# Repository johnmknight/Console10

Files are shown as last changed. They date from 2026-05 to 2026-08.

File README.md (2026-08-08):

<p align="center">
  <picture>
    <source media="(prefers-color-scheme: dark)" srcset="branding/console10_logo_dark.png">
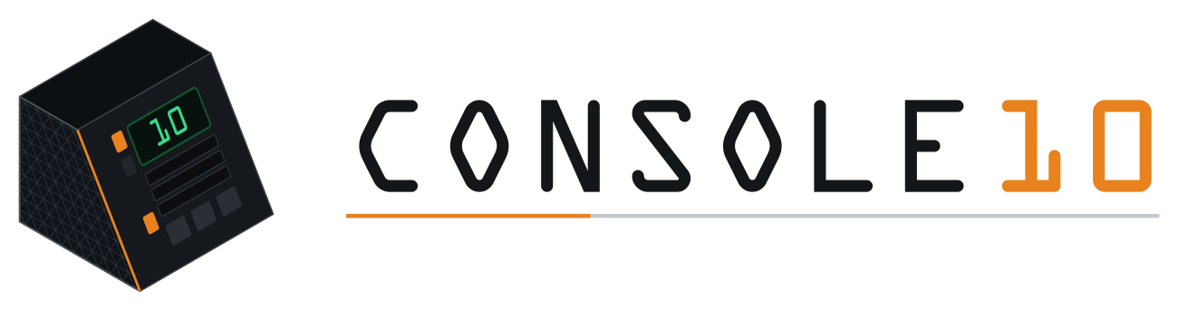
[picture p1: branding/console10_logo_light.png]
CONSOLE10
    
  </picture>
</p>

# Console10

Modular desktop **10" mini-rack housing system**, styled after NASA Mission Operations Control Room consoles. Each module is a self-contained 3D-printed enclosure that houses small-form-factor 10" mini-rack equipment (Pi mounts, small routers, Stream Decks, mini displays).

See `designdoc.md` (**v3.3**) for the full specification, including the accessory faceplates (§15–17).

## Architecture (v3.0)

A module is **4 printed parts**: 2 isogrid **cheeks** + a one-piece **top** + a one-piece **bottom**. The back is an open equipment plane. The **front slant insert is an accessory**, not a cabinet part — see "Cabinet vs. accessories" below. (Corrected 2026-08-01; previously read "5 printed parts".)

The v2.4–v2.5 split-half + centerline-dovetail panel scheme is **abandoned**. Top and bottom are now **single-piece** panels whose width aligns with the 10" mini-rack standard (~253 mm) — so each prints as **one part on a 255 mm bed**. Joinery is **rabbet-based** (no dovetail):

- **Bottom** → raised side ridges seat into **rabbets in the cheek bottom edges**.
- **Top** → a rabbet receives each **cheek's top edge**.
- Secured with glue or fasteners (TBD).

## Cabinet vs. accessories

**"Console10" = the cabinet only**: 2 cheeks + top + bottom. Everything
that mounts to it — display faceplates, the MacroPad panel, the screen/slider panel, blank
fillers, the Gridfinity drawer — is a **swappable accessory faceplate** that bolts to the
cheek **slant inserts** (front) or **back-edge inserts**. Panels are sized to the rack U
grid and the ~253 mm width. `Console10_module.scad` is the fit-check assembly that places
the cabinet + a chosen accessory on the slant.

### Accessory faceplates (current)

| File | Accessory | Mount | Status |
|---|---|---|---|
| `Console10_display_faceplate.scad` | 7" monitor faceplate (Elecrow RC070 / GeeekPi) | 3U slant | v0.17 |
| `Console10_lower_blank_faceplate.scad` | Blank filler beneath the display | 2U slant | v0.1 |
| `Console10_macropad_pair_faceplate.scad` | 2× MacroPad + 0.91" OLED + 6 switch guards | 3U slant | v0.5 |
| `Console10_screen_slider_panel.scad` | 4" HyperPixel sq + NeoSlider fader + OLED + 3 toggle guards | 3U | v0.1 |
| `Console10_dsky_panel.scad` | DSKY-style: HyperPixel + MacroPad + slider + OLED | 3U | v0.1 |
| `Console10_drawer.scad` | Gridfinity slide-out drawer | 2U | WIP v0.1 |
| `Console10_phone_2u_faceplate.scad` | Pixel 10 Pro XL dock: charger puck + eject lever (see `HANDOFF-phone-2u-faceplate.md`) | 2U slant @ s=133.35 | v0.2 |
| `Console10_b860i_faceplate.scad` | ASUS B860-I rear-I/O cover plate (truenas2) | 2U | v0.1 |

Plus assorted blanks / holders (`Console10_aux_2u_faceplate`, `..._bluray_2u_faceplate`,
`..._lcd_simple_faceplate`, `..._sd_holder_handled`, `..._bit_holder_handled`, etc.).

## Repository layout / file status

| File | Role | Status |
|---|---|---|
| `designdoc.md` | Design spec | ✓ v3.3.1 |
| `README.md` | This file | ✓ synced to v3.3.1 (2026-07-28) |
| `Console10_isogrid.scad` | **Cheek** (parametric source) | ✓ v3.1 — rabbets on both top & bottom edges (old v2.4 tab-channels removed) |
| `Console10_isogrid_vent.scad` | Cheek variant: isogrid field cut THROUGH for airflow (drop-in `cheek()` swap; mirrors `Console10_isogrid.scad` — keep in sync) | ✓ v3.0-vent · export `stl/Console10_cheek_vent.stl` |
| `Console10_top.scad` | **Top** panel (parametric source) | ✓ v3.1 |
| `Console10_bottom.scad` | **Bottom** panel (parametric source) | ✓ v3.1 |
| `Console10_front_insert.scad` | **Front** insert (parametric source) | ✓ v3.1 |
| `stl/Console10_cheek.stl` · `stl/Console10_top.stl` · `stl/Console10_bottom.stl` · `stl/Console10_front_insert.stl` | **Current exports — print these** | ✓ 2026-05-28 |
| `NEW_NASA_TOP.stl` · `new_nasa_bottom.stl` · `NASA_Insert_Front.stl` | Reference STL models | superseded by the `.scad` parts |
| `Console10_isogrid-new.stl` | Older cheek export (2026-05-17) | superseded by `stl/Console10_cheek.stl` |
| `Console10_isogrid-do-not-delete.stl` | Old 6 mm cheek | superseded |
| `Console10_top_panel_half.scad` | Split-half top | ✗ DEPRECATED |
| `Console10_bottom_panel_half.scad` | Split-half bottom | ✗ DEPRECATED |
| `Console10_module.scad` | Full fit-check assembly (cabinet + accessory faceplates) | ✓ built |
| `preview/` | Rendered previews | — |
| `marketing/` | Promo materials: storyboard, shot board, video brief | — |
| `wip/` | Scratch: animation runs, logs, backups (untracked except `_parts.py`) | local only |

## Standards (locked)

- **10" mini-rack** (EIA-310-D): 1U = 44.45 mm; rail-to-rail = 236.525 mm; per-U holes at 6.35 / 22.225 / 38.10 mm
- **Equipment mounting**: 10-32 brass heat-set inserts in the cheek edge faces (24 per cheek)
- **Capacity**: 4U (C4)
- **Target bed**: 255 × 255 × 255 mm (all parts single-piece)

## Module dimensions (v3.0)

| Dimension | Value |
|---|---|
| Cheek silhouette | Right trapezoid, slant on FRONT |
| Bottom / depth | **228.6 mm** |
| Back-edge height | **205.45 mm** |
| Top-edge length | **109.975 mm** |
| Front (slant) length | **237.25 mm** |
| Slant angle | **30° from vertical** (isogrid-aligned) |
| Cheek thickness | **10 mm** |
| Top/bottom panel width | **~253 mm** (10" mini-rack standard, single-piece bed-fit) |

## Parts list (4 printed parts + accessories)

**The cabinet — this is what "four printed parts" means:**

| Part | Count | Print orientation |
|---|---|---|
| Cheek (L + R mirror) | 2 | Flat, exterior face down, isogrid up |
| Top panel | 1 | Flat (support rabbet overhang as needed) |
| Bottom panel | 1 | Flat (support ridge overhang as needed) |

**Accessories — printable and legitimate, but never counted in the cabinet:**

| Part | Count | Print orientation |
|---|---|---|
| Front slant insert | 1 | Wedge oriented for minimal support |
| Slant cap | 1 | Glue-on filler; only meaningful with a display faceplate |
| Faceplates (display / macropad / blank / …) | n | See the accessory table above |

*Corrected 2026-08-01 — this heading read "(5 printed parts)" and the table listed the
front insert as a cabinet part. The authoritative lists are `CABINET_PARTS` and
`ACCESSORY_PARTS` in `Console10_module.scad`, which `wip\_parts.py` parses with no
fallback, so any render's part count now comes from the SCAD rather than from this table.*

## OpenSCAD usage

```
openscad Console10_isogrid.scad     # cheek (parametric)
openscad Console10_module.scad      # full fit-check assembly (built)

# headless export of the whole cabinet, no faceplates:
openscad -o module.stl -D show_front=true -D show_macropad=false \
         -D show_display=false -D show_lower_blank=false Console10_module.scad
```

**All four cabinet parts are parametric SCAD** as of v3.1 — `Console10_isogrid.scad`, `Console10_top.scad`, `Console10_bottom.scad`, `Console10_front_insert.scad`. `Console10_module.scad` `use<>`s all four and places them; that file is the authority on how the parts seat. Current exports are in `stl/`. The root-level `NEW_NASA_TOP.stl`, `new_nasa_bottom.stl` and `NASA_Insert_Front.stl` are the earlier hand-modelled generation, kept for reference only — they are not byte-identical to the current exports even where bounding boxes match, so don't print from them.

## Open items

See `designdoc.md` §13. Highlights: reconcile final width vs rabbet geometry; finalize glue vs fasteners; first-print validation of the 0.4 mm ridge/rabbet clearance; decide front-insert merge-into-bottom vs standalone + glue.

Closed since this list was written: the cheek tab-channels **were** replaced with rabbets (v3.1, both top and bottom edges), the front wedge **is** 30° and mates flush, and `Console10_module.scad` **is** built.

Closed 2026-08-01: `Console10_module.scad` used to draw `slant_cap_on_slant()` unconditionally; it is now gated behind `show_slant_cap` (default off — only meaningful with `show_display` on).

## Variants

- **C4** (4U, current) · C2 (2U, future) · C6 (6U, future) · C4-E (sci-fi etched, deferred)

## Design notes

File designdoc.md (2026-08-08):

# CONSOLE10 — DESIGN DOCUMENT

**Version 3.3.1**
**Date: 2026-07-28**

---

## v3.3.1 changelog — documentation only, no geometry change

An audit against the files on disk found the doc contradicting itself in four places.
No part was modified; only the descriptions of them.

1. **§3.1 parts table** pointed at the superseded root-level STLs (`NEW_NASA_TOP.stl`,
   `new_nasa_bottom.stl`, `NASA_Insert_Front.stl`, `Console10_isogrid-new.stl`) while §7
   and §12 said the parametric `.scad` files supersede them. Now points at `stl/`, which
   holds the current exports.
2. **§9.2** listed the top as 16 mm thick and the front insert as 237.3 × 20.6 — the
   dimensions of the *old* STLs, contradicting §7. Corrected to the measured current
   parts (top 10 mm; insert 232.6 × 21.9 × 38).
3. **§12** labelled this file "✓ v3.1" while the header said v3.3, and omitted `stl/`
   entirely. Both fixed.
4. The **slant cap** (`Console10_slant_cap.scad`) was undocumented. It is an *accessory*,
   not a fifth-part-plus-one: a glue-on filler for the gap between the top panel and the
   top of a fitted display faceplate. `Console10_module.scad` used to draw
   `slant_cap_on_slant()` **unconditionally**, with no `show_` flag — fixed alongside this
   audit: it is now gated behind `show_slant_cap` (default off, since it is only
   meaningful when `show_display` is on).

## v3.3 changelog (vs v3.1)

1. **Top front bevel** added (built cleanly via `hull()`) — the top's front edge rakes to the 30 deg slant.
2. **M3 mounting screws**: socket-cap, **counterbored flush** — top **3/side**, bottom **4/side**, centered over each cheek — driving into **M3 heat-set inserts** in the cheek top + bottom edges.
3. **Tongue & groove equalized**: tongue + both walls all equal at 10/3 (~3.33 mm), centered (was a 4 mm tongue offset to the inside, unequal walls).
4. **Isogrid moved to the EXTERIOR face**, **5 mm deep** (was 1.8 mm on the interior), with the **outer ring filled solid** (`iso_edge_fill`, ~half a triangle spacing) so the deeper pockets clear the edge rabbets / inserts / rail holes.

## v3.1 changelog (vs v3.0)

1. **All parts are now parametric OpenSCAD**: `Console10_top.scad`, `Console10_bottom.scad`, `Console10_front_insert.scad` (reverse-engineered from the NASA STL models), plus the existing cheek `Console10_isogrid.scad` and an assembly `Console10_module.scad`.
2. **Symmetric ridge joinery**: the TOP now uses the SAME joinery as the bottom — a slab with two side ridges that seat into rabbets in the cheek **top** edge. The v3.0 top "wall + slot" scheme is dropped. The cheek now has a rabbet on **both** the top and bottom edges.
3. **Front insert** now spans BETWEEN the cheeks (~232.6 mm), sitting on the floor at the front, with its 30° face flush with the slant (was modeled as a slant-length wedge).
4. A 30° bevel on the top's front edge was tried and reverted here (re-added cleanly in v3.3).

## v3.0 changelog (vs v2.5) — MAJOR ARCHITECTURE CHANGE

The split-half + dovetail-castellation panel scheme (v2.4–v2.5) is **abandoned**. Top and bottom are now **single-piece panels** sized to the 10-inch mini-rack standard width, and joinery is **rabbet-based**, not centerline-dovetail.

1. **Top & bottom panels are one piece each** — no L/R split, no centerline dovetail. Their width now aligns with the **10" mini-rack standard (~253 mm)**, so each panel **prints as a single part on a 255 × 255 × 255 mm bed**. The bed-fit split that drove the v2.4 dovetail design is no longer needed.
2. **Joinery is now rabbet-based** (replaces cheek tab-channels + centerline dovetail):
   - **Bottom**: a **raised ridge along each side** seats into a matching **rabbet in the cheek's bottom edge** (one ridge per side).
   - **Top**: a **rabbet** on the top that **each cheek's top edge sits into**.
   - Final hold: **glue or fasteners** (type TBD).
3. **Front insert added** (`NASA_Insert_Front.stl`): a slant-length wedge **template** that can either be **merged into the bottom** part or **printed standalone and glued** along the slant.
4. **Top / bottom / front are now standalone STL models**, not SCAD-generated. The **cheek remains SCAD-driven** (`Console10_isogrid.scad`).
5. **Deprecated**: `Console10_top_panel_half.scad`, `Console10_bottom_panel_half.scad`, the centerline dovetail (old §8), and the cheek top/bottom **tab-channels** (old §6) — the cheek now needs **rabbets** instead of channels (SCAD update pending, see §12).

(Changelogs v2.1–v2.5 retained in §14 for history.)

---

## 1. What we're building

Console10 is a modular 10-inch mini-rack housing for desktop equipment, 3D-printed in PLA, styled after Apollo-era NASA mission-control hardware.

A module is **four printed parts**: two trapezoidal isogrid **cheeks** (L/R sides), a single-piece **top** panel, and a single-piece **bottom** panel. The **back** face is an open equipment-mounting plane; 1U faceplates are user-installed. The **front slant** is also a mounting plane.

The **front slant insert** is an **accessory**, not a cabinet part — optional filler/template for the front slant, in the same category as the slant cap and the faceplates. Corrected 2026-08-01; this line previously read "five printed parts" and counted the insert. The authoritative lists live in `C:\Users\john_\dev\Console10\Console10_module.scad` as `CABINET_PARTS` and `ACCESSORY_PARTS`, which `C:\Users\john_\dev\Console10\wip\_parts.py` parses with no fallback — so the count in any render now comes from the SCAD rather than from prose. (Local, untracked backup of the previous version: `wip\_pre0801_designdoc.md.bak`, sha256 prefix `410F8B750A28F9A8` — `*.bak` is gitignored, so it exists only on JOHN-S-PC.)

Panels register to the cheeks via **rabbet joinery** (§6–7) and are secured with glue or fasteners.

---

## 2. Standards compliance

- **Mounting standard**: EIA-310-D 10-inch mini-rack
- **1U height**: 44.45 mm
- **Per-U hole pattern**: 3 holes at offsets 6.35, 22.225, 38.10 mm
- **Capacity**: 4U (C4 variant)
- **Rail-to-rail hole spacing**: 236.525 mm
- **Panel width**: aligned to the 10" mini-rack standard (~253 mm)

---

## 3. Module architecture

### 3.1 Parts list (5 parts per module)

| Part | Count | File (current) | Source | Role |
|---|---|---|---|---|
| Cheek | 2 | `stl/Console10_cheek.stl` | `Console10_isogrid.scad` | Side panel, right-trapezoid, isogrid, 10 mm thick |
| Top | 1 | `stl/Console10_top.stl` | `Console10_top.scad` | Caps the top edge; ridges seat into the cheek top-edge rabbets |
| Bottom | 1 | `stl/Console10_bottom.stl` | `Console10_bottom.scad` | Floor; raised side ridges seat into cheek bottom-edge rabbets |
| Front insert | 1 | `stl/Console10_front_insert.stl` | `Console10_front_insert.scad` | Slant filler spanning between the cheeks; merge into bottom or print standalone + glue |

**Current exports live in `stl/`.** The root-level `Console10_isogrid-new.stl` (2026-05-17),
`new_nasa_bottom.stl`, `NEW_NASA_TOP.stl` and `NASA_Insert_Front.stl` (all 2026-05-28 morning)
predate the parametric sources and are retained for reference only — see §12. They are NOT
byte-identical to the current exports even where the bounding boxes match, so do not print
from them.

No split halves, no separate rails, no centerline dovetail. Rail-mount holes are integral to each cheek's edge faces (§5).

### 3.2 Material

Default **PLA**. PETG/ASA acceptable for cheeks. (Solvent-bond requirement from the old dovetail design no longer applies; bonding is now at the rabbet interfaces if glue is used.)

### 3.3 Hardware BOM (per module)

| Item | Count | Use |
|---|---|-----|
| 10-32 brass heat-set inserts | 48 | Equipment mounting (24 per cheek: 12 slant + 12 back) |
| Glue or fasteners | as required | Top/bottom-to-cheek at the rabbet interfaces (type TBD) |

---

## 4. Cheek

### 4.1 Silhouette (LOCKED, unchanged)

Right trapezoid, slant on the **front** edge.

| Edge | Length (mm) |
|---|---|
| Bottom | 228.6 |
| Back (vertical) | 205.45 |
| Top | 109.975 |
| Slant (front) | 237.25 |
| Slant angle | 30° from vertical (isogrid-aligned) |

### 4.2 Thickness — 10 mm

Hosts ~8 mm-deep edge-drilled 10-32 inserts with adequate wall material.

### 4.3 Isogrid (v2.5)

- Tiling: {3, 6} triangular · Spacing: 20 mm · Rib: 2.5 mm · **Pocket depth: 5 mm** (or through-cut) · Fillet: 1.59 mm
- **Face: EXTERIOR** (v3.3 — pockets are on the outside face; interior is flat)
- Coverage: **whole-triangle filter** + **outer-ring fill** — a pocket is generated only when all three triangle vertices fall inside the silhouette inset by `iso_edge_fill` (~half a spacing). This fills the outer ring(s) solid so the 5 mm pockets clear the edge rabbets / inserts / rail holes.

### 4.4 Cheek edge features for panel joinery (v3.0 — pending SCAD update)

- **Bottom edge**: a **rabbet** to receive the bottom panel's raised side ridge.
- **Top edge**: seats into the rabbet on the top panel (the cheek top is the male feature here).
- NOTE: the current `Console10_isogrid.scad` still models the **old tab-channels** (`top_channel()` / `bottom_channel()`) on these edges. These must be replaced with rabbets to match v3.0. See §12.

---

## 5. Equipment mounting (cheek edges)

Rack equipment mounts via flanged rack ears bolted directly to the cheek **edge face**, into heat-set inserts in the cheek thickness. The cheek edge IS the mounting surface — no separate rail.

### 5.1 Slant edge rail
- 12 × 10-32 insert holes, axis perpendicular to slant face, EIA-310 pattern, 4U, 1U bottom gap, 15 mm top margin.
- Positions along slant from front-bottom corner (mm): `50.80, 66.675, 82.55, 95.25, 111.125, 127.00, 139.70, 155.575, 171.45, 184.15, 200.025, 215.90`
- Hole: 4.2 mm dia (10-32 pilot), 8 mm deep.

### 5.2 Back edge rail
- 12 × 10-32 insert holes, axis perpendicular to back face, EIA-310 pattern, 4U from floor.
- Positions from floor (mm): `6.35, 22.225, 38.10, 50.80, 66.675, 82.55, 95.25, 111.125, 127.00, 139.70, 155.575, 171.45`
- Same hole dia/depth as slant.

---

## 6. Cheek ↔ panel rabbet joinery (replaces old §6 channels + §8 dovetail)

- **Bottom**: raised ridge on each side of the bottom panel → rabbet in the cheek bottom edge. Registers the floor laterally and locates the cheeks.
- **Top**: raised ridge on each side of the top panel → rabbet in the cheek **top** edge (symmetric with the bottom — same joinery both ends).
- **Securing**: glue or fasteners across the rabbet interfaces (TBD).
- Exact ridge/rabbet dimensions and clearances: **TBD** — to be set when the cheek SCAD is updated and the panels are dimensioned against it.

---

## 7. Top, bottom, and front parts (measured, as-modeled)

| Part | W × D × H (mm) | Notes |
|---|---|---|
| **Top** (`Console10_top.scad`) | 253 × 109.975 × 10 | Slab (6 mm) + two 4×4 side ridges. Ridges seat into the cheek **top** rabbets (flipped in the module). One-piece. |
| **Bottom** (`Console10_bottom.scad`) | 253 × 228.6 × 10 | Slab (6 mm) + two 4×4 side ridges → cheek **bottom** rabbets. One-piece. |
| **Front insert** (`Console10_front_insert.scad`) | ~232.6 × 21.94 × 38 | Triangular wedge spanning BETWEEN the cheeks, on the floor at the front; 30° face flush with the slant. Print standalone + glue, or merge into the bottom. |

(The original `NEW_NASA_TOP.stl` / `new_nasa_bottom.stl` / `NASA_Insert_Front.stl` models are retained for reference; the parametric `.scad` files above supersede them.)

The 253 mm width aligns with the 10" mini-rack standard and fits a 255 mm bed as a single part — no split required.

---

## 8. Centerline joint — REMOVED

The v2.4–v2.5 trapezoidal dovetail castellation at the panel centerline is **superseded** by the single-piece panels + rabbet joinery (§6). There is no centerline split in v3.0.

---

## 9. Manufacturing

### 9.1 Print bed
255 × 255 × 255 mm (also fits Bambu A1/P1/X1 256 mm class).

### 9.2 Fit on bed (all single-piece)

| Part | Footprint (mm) | Thickness/Height | Fits 255 bed |
|---|---|---|---|
| Cheek | 228.6 × 205.45 | 10 mm | ✓ |
| Top | 253.0 × 110.0 | 10 mm | ✓ |
| Bottom | 253.0 × 228.6 | 10 mm | ✓ |
| Front insert | 232.6 long | 21.9 × 38 | ✓ |

(Measured from the current `stl/` exports, 2026-07-28. The earlier "Top 16 mm" and
"Front insert 237.3 long × 20.6" figures described the superseded root-level STLs and
contradicted §7; both now agree.)

### 9.3 Print orientation
- **Cheek**: flat on bed, **interior face down** (the isogrid is now on the exterior, so its pockets face up — no overhang). M3 insert holes in the top/bottom edges; rail holes in the slant/back edges.
- **Top / bottom**: flat on bed (rabbet/ridge features may need light support depending on orientation).
- **Front insert**: orient wedge for minimal support.

### 9.4 Suggested settings (PLA)
- 0.2 mm layers, 25–40% infill, 3–4 walls, supports as needed for rabbet/ridge overhangs.

---

## 10. Module exterior dimensions

| Dimension | Value (mm) |
|---|---|
| Depth (bottom front-to-back) | 228.6 |
| Height (back edge) | 205.45 |
| Slant length | 237.25 |
| Top edge length | 109.975 |
| Top/bottom panel width | ~253 (10" mini-rack standard) |

(Old v2.x interior/exterior width figures of 261.525 / 281.525 are superseded; reconcile final width against the rabbet geometry — see §13.)

---

## 11. Variants

| Variant | Description | Status |
|---|---|---|
| **C4** | 4U, standard | current |
| C2 | 2U (shorter) | future |
| C6 | 6U (taller) | future |
| C4-E | C4 with sci-fi etching | deferred |

---

## 12. Files

| File | Status |
|---|---|
| `designdoc.md` (this file) | ✓ v3.3.1 |
| `stl/` — **current exports**: `Console10_cheek.stl`, `Console10_top.stl`, `Console10_bottom.stl`, `Console10_front_insert.stl` | ✓ exported 2026-05-28 13:36 from the parametric sources |
| `stl/All-Parts.3mf` | slicer project (ignored by git — `*.3mf`) |
| `stl/nasa switch  guards/` | printable toggle-switch guards |
| `Console10_slant_cap.scad` / `_tall` | accessory: glue-on filler closing the slant between the top panel and the top of the display faceplate. NOT a cabinet part — only needed when a display faceplate is fitted |
| `README.md` | ✓ (v3.0 layout; minor v3.1 joinery sync pending) |
| `Console10_isogrid.scad` (cheek) | ✓ v3.1 — silhouette/isogrid + rabbets on both top & bottom edges |
| `Console10_top.scad` | ✓ v3.1 — slab + side ridges (parametric) |
| `Console10_bottom.scad` | ✓ v3.1 — slab + side ridges (parametric) |
| `Console10_front_insert.scad` | ✓ v3.1 — front wedge, spans between cheeks (parametric) |
| `Console10_module.scad` | ✓ v3.1 — fit-check assembly (use<> all parts) |
| `NEW_NASA_TOP.stl` / `new_nasa_bottom.stl` / `NASA_Insert_Front.stl` | reference STL models (superseded by the `.scad` parts) |
| `Console10_top_panel_half.scad` / `..._bottom_panel_half.scad` | ✗ DEPRECATED (split-half design) — safe to delete |
| `Console10_isogrid-do-not-delete.stl` | old 6 mm cheek (superseded) |

---

## 13. Open items

- **Reconcile module width**: panels are 253 mm; confirm final interior/exterior width and rabbet engagement against the cheeks (old 261.525 interior is superseded).
- **Front insert**: decide merge-into-bottom vs standalone + glue.
- **Securing method**: finalize glue vs fasteners for top/bottom-to-cheek.
- **Ridge/rabbet fit clearance**: first-print validate the 0.4 mm clearance.
- **Shared params**: consider a `Console10_params.scad` so the ridge/rabbet dims can't drift between the cheek and the panels.
- **MiniRax faceplates** (`MiniRaxFacePlate1.stl`, `MiniRax-plain-mini-faceplate.stl`): integrate / parameterize as needed.

---

## 15. Slide-out Gridfinity drawer — WIP v0.1 (2026-05-30)

A 2U slide-out drawer for the module BOTTOM whose floor is a true Gridfinity
baseplate. New file: `Console10_drawer.scad` (parametric; `part =
"faceplate"|"drawer"|"assembly"`). Compiles clean + manifold in OpenSCAD;
fit-check previews at `preview/drawer_assembly_iso.png` / `_side.png`.

**Architecture (locked with John):** faceplate-anchored, no floor hardware.
- The **faceplate** is a 30° slanted bezel that bolts to the cheek **slant** rack
  inserts (2 screws/side). Its two **C-channel slide rails are integral**, running
  back along the floor into the cavity. It REPLACES `Console10_front_insert` on a
  drawer module.
- The **drawer** is a 5×4 Gridfinity box (210×168 mm field, standard 4.75 mm
  interface) with side **tongues** riding the rails; its own 30° front nests
  flush in the faceplate mouth (finger-pull slot).

**Key params (as built):** face 247×87.9 mm, mouth 222×74 mm; drawer body
220×183 mm; rail 8 mm / 6 mm slot, tongue 4×5 mm, `run_gap` 0.5; Gridfinity
pitch 42, no-magnet "lite" baseplate.

**NEXT STEPS to make it print-ready (none are open design questions):**
1. **Drawer stop** — add a rear bump-stop in the rails + a removable front
   retainer so the drawer can't pull fully out. (Not yet modeled.)
2. **Rail overhang** — the C-channel lip overhangs its slot; add a 45° chamfer
   under the lip and/or a split-rail print option. Decide print orientation.
3. **Fit validation (first article):** tongue/slot `run_gap` and the Gridfinity
   pocket fit are first-print tuning items.
4. **Docs:** fold this into the README parts table + a designdoc v3.4 changelog
   and the variants list once the geometry is frozen.

**State:** `Console10_drawer.scad` is untracked (not committed). Previews are new
files in `preview/`. Nothing else in the repo was changed.

---

## 16. Twin-MacroPad lower faceplate — v0.4 (2026-06-14)

A plain 2U faceplate (`Console10_macropad_pair_faceplate.scad`; `part =
"panel" | "mount_board" | "macropad_backplate"`) carrying **two Adafruit 5128
MacroPad RP2040s** mounted end-to-end, each rotated 90° so the long axis runs
across the panel (OLED/encoder ends out at the far left/right, PCBs butt at the
centre seam). Each board drops into a rear pocket+collar; keys stay proud through
the front.

**Two bolt circles per pad (this is the key geometry).** The MacroPad's own PCB
holes and the panel's backplate posts are **deliberately not concentric**:
- **PCB mounting holes** — pitch `mp_hx,mp_hy` = 52.07 × 81.28 mm (±26.04 × ±40.64),
  **but the 4-hole pattern is NOT centred on the board.** Measured from the 5128
  assembly STL (cross-sectioned + overlaid in OpenSCAD — *measure from the model,
  not photos*), it sits **`mp_hy_off` = +7.65 mm toward the OLED/encoder (+Y) end**.
  Holes are at (±26.04, ±40.64 **+ 7.65**). The earlier v0.2 board placed the
  standoffs centred, so they missed every hole by ~7.6 mm and the two pads could
  not be mounted back-to-back — this is the v0.3 fix.
- **Panel posts** — `mp_post_sx,mp_post_sy` = ±38 × ±44, pushed *outboard* of the
  pocket/collar wall (which reaches 32.65) so a backplate can bolt to the panel
  clear of the board. A Ø7 post can't sit on the PCB-hole axis without fouling the
  board, so the two circles stay offset by ~12 mm (across) / ~3.4 mm (along).
  (Seen edge-on this reads as "posts offset from the MacroPad holes" — it's by
  design, not a bug.)

**Mounting board — v0.3 (NEW, replaces the two loose per-pad backplates).**
`macropad_mount_board()` is **one** printed plate spanning both pads (~213 × 88 ×
4 mm) that **bridges** the two bolt circles:
- 8 × Ø3.4 flush holes on the post circle → bolts **down** onto all 8 panel posts.
- 8 × Ø7 standoffs (8.4 mm tall, Ø3.4 thru) on the **offset** PCB circle → screw
  **up** into the two PCBs (board bottom at z = −19, top on the post tips at
  z = −15, standoffs reach the PCB back at z = −6.6). The standoffs carry the
  `+mp_hy_off` shift, so the OLED-end pair lands ~3.8 mm from the board end →
  plate widened to ±106.4 mm to support them.
- Validated by overlaying the standoff centres on the STL PCB cross-section:
  residual < 0.1 mm at all 4 holes.
- Single welded solid, `Simple: yes`. Print flat-side down / standoffs up, no
  supports. Exported STL: `Console10_macropad_pair_backplate.stl`.
- The older per-pad `macropad_backplate()` is kept in-file for reference only
  (note: it still uses the *centred* hole assumption and is superseded).

**Possible next steps (not open design questions):** USB-C end relief at the
widened ends, a central lightening cutout, and/or a keyed corner; first-article
fit check of standoff height vs PCB seat and the post screw engagement.

**v0.4 changes (2026-06-14):**
- **Front lip cut flush to the PCB edge on both axes** (`mp_face_w = mp_pocket_w`,
  `mp_face_h = mp_pocket_h`). The old 56 × 100 opening left a ~2 mm lip overhanging
  the outer key columns (blocked keycaps) and the OLED/encoder ends (blocked the
  display). No front lip now — retention is the rear mount board; the centre
  divider stub is gone so the two openings read as one.
- **Extended 2U → 3U** (`n_u = 3`, 133.35 mm). MacroPads pushed to the TOP
  (`mp_cy = plate_h − U` = 88.9) with a blank skirt below, so the rear mount-board
  assembly sits high and **clears the shelf/floor** when mounted below a 7" monitor
  (the 2U rear stack collided with the floor). Mount rows → 3U `[50.80, 127.00]`.
  Re-exported `Console10_macropad_pair_faceplate.stl`.

**v0.5 changes (2026-06-14):**
- **0.91" OLED status display + a row of 6 switch-guard mounts** added in the lower
  skirt below the keys: 1 guard under the left MacroPad + 5 right-aligned (rightmost's
  right side at the screen/MacroPad right edge); the OLED is centred BENEATH the first
  (left) switch as its status readout. Panel carries only the 12 mm bushing holes +
  square base recesses (shuttle guards printed separately, glued in); the OLED gets a
  recessed pocket/window + 4 rear posts.
- **MacroPad face openings squared** (rounded-rect → plain rectangle).
- **Assembly:** `Console10_module.scad` now places the panel on the slant via
  `macropad_pair_on_slant()` — top edge at the 6th–7th slant-hole midpoint (s = 133.35),
  base at the front-bottom corner; `show_macropad` / `show_cheeks` toggles added.

## 17. Screen + Slider + OLED + guarded-toggle faceplate — v0.1 (2026-06-14)

A 3U faceplate (`Console10_screen_slider_panel.scad`; `part = "panel" |
"hyperpixel_backplate"`) — derived from the DSKY concept (`Console10_dsky_panel.scad`)
with the MacroPad removed — carrying four device groups:

- **Pimoroni HyperPixel 4.0 Square** (720×720 touch) — recessed pocket + front
  window lip; 2-stem rear backplate (below).
- **Adafruit NeoSlider 5295** vertical fader — metal housing **9.4 × 75.1 mm**
  (measured; CAD STEP 9.5 × 75.0), **SQUARE** flush cutout so the rectangular
  housing seats flush to the panel face (top at z = plate_t), knob proud.
- **Adafruit 0.91" 128×32 OLED 4440** — recessed in a **module-sized pocket** (the
  display module is bigger than the active window) so the glass sits ~0.5 mm behind
  the front lip; 4-screw rear mount, active area centred on the hole pattern.
- **3 × guarded toggle switches** in a row below the screen — COROTC SPST (12 mm
  bushing) + the printable "Space Shuttle Toggle Switch Guard" (ImAThingsGuy, public
  domain, 25 × 25 × 30 mm). Panel has a 12.4 mm bushing hole + a **square recess**
  for the guard base (anti-rotation), guards oriented rings-vertical. Screen raised
  to the top to clear the toggle row.

**Component dims pulled from Adafruit STEP CAD** (`Adafruit_CAD_Parts` repo), parsed
directly: NeoSlider holes **38.1 × 16.51** (the earlier 70-along value was wrong and
would have missed the PCB holes), OLED holes 27.94 × 16.51, OLED active 22.384 × 5.584.

**HyperPixel backplate** (`part = "hyperpixel_backplate"`): per the board photo, only
the **2 HAT holes on the FPC edge are usable** (the GPIO header + ribbon block the
other 2), so it mounts on 2 stems and bolts to 4 panel posts; a **cable slot runs out
through the GPIO edge** (open U) for the 40-pin IDC + ribbon.

STLs: `Console10_screen_slider_panel.stl`, `Console10_screen_slider_hp_backplate.stl`.
The toggle guard prints from the downloaded `space-shuttle-switch-guard.stl`.

**Open items:** HyperPixel HAT-hole positions still `[verify]`; guard cap is glue-on
(no non-rotating press-fit); confirm the GPIO cable-exit edge.

## 14. Revision history

- **v2.0** — project reset
- **v2.1** — geometry locked (silhouette, isogrid)
- **v2.2** — slant moved to front; rails integrated into cheeks; finger joint at centerline
- **v2.3** — slant angle set to 30° for isogrid alignment
- **v2.4** — major simplification: cheek 6→10 mm; rail holes to cheek edge faces; backing strips removed; panels tray→flat-panel-with-tabs; cheek channels added; centerline castellation rectangular→trapezoidal 30° (Apollo 13 ref); tab protrusion 12→6 mm; centerline joinery → PLA solvent/glue dovetail (no screws/inserts)
- **v2.5** — isogrid pocket filter (whole-triangle, no clipped perimeter pockets)
- **v3.0** — **major architecture change**: abandoned the split-half + centerline dovetail; top & bottom are now **single-piece** panels sized to the 10" mini-rack width (~253 mm), printable as one part on a 255 mm bed; joinery changed to **rabbet-based** (bottom side-ridges into cheek bottom rabbets; cheek tops into a top-panel rabbet); **front insert** added as a slant wedge template (merge into bottom or glue); top/bottom/front are now standalone STL models, cheek remains SCAD-driven; deprecated the `*_panel_half.scad` files and cheek tab-channels
- **v3.1** — all parts re-authored as parametric OpenSCAD (top/bottom/front/cheek + module assembly); symmetric ridge joinery (top now matches the bottom: slab + side ridges into cheek top rabbets; cheek rabbeted on both edges); front insert spans between the cheeks; a top front-edge bevel was tried and reverted
- **v3.3** — top front bevel re-added (hull-built); M3 counterbored socket-cap mounts (top 3/side, bottom 4/side) into heat-set inserts in the cheek edges; tongue/groove equalized to 10/3 (~3.33 mm) all-equal/centered; isogrid moved to the exterior face, 5 mm deep, outer ring filled (`iso_edge_fill`)

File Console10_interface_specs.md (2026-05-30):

# Console10 — Faceplate Interface Reference

Measured/derived dimensions for every device interface used across the Console10 faceplates. Each entry includes the source device, measured envelope, panel cutout (with clearance), and any rear-side support / retention features. Pull from this file when designing a new faceplate.

All dimensions in **mm** unless noted.

---

## Slant-insert mount holes (every faceplate)

Bolts the panel to the cheek slant inserts.

| | Value |
|---|---|
| Hole diameter | 5.5 (10-32 clearance) |
| X positions | ±121.5 (`±cheek_ctr_x`) |
| Y positions (3U plate, 133.35 tall) | 50.80, 127.00 |
| Y positions (2U plate, 88.9 tall) | 50.80, 82.55 |

Y positions are along-slant `s`, derived from `front_gap=U=44.45 + u_idx*U + EIA{6.35, 22.225, 38.10}`. Skip `s=22.225` — it's inside the front_gap and has no cheek hole.

---

## CF card reader (press-fit + full-depth open sleeve)

USB CF card reader, slim vertical form. Press-fit retention only, no screws.

| | Value |
|---|---|
| Body W × H × D | 13.8 × 65.9 × 30 |
| Panel cutout | 13.8 × 65.9 (sharp corners) — `cf_press_clr = 0` |
| Rear sleeve | wraps body for full depth, **open both ends** |
| Sleeve wall thickness | 2.5 (`cf_wall_t`) |
| Sleeve outer | 18.8 × 70.9 × 30 |

If press-fit feels loose after print, set `cf_press_clr` negative (e.g., `-0.1`).

---

## SD card holder (press-fit + closed-back sleeve, sits proud)

Custom 3D-printed holder (STL: `SD card holder 1x1x3.stl`). Slides into the panel from the front, bottoms on the sleeve floor leaving the body sitting proud so the user can grab it.

| | Value |
|---|---|
| Body W × H × D | 41.5 × 41.5 × 24.54 |
| Panel cutout | 41.5 × 41.5 (sharp corners) — `holder_press_clr = 0` |
| Proud height when bottomed | 5 (`holder_proud`) |
| Sleeve wall + floor thickness | 2.5 (`holder_wall_t`) |
| Extra cavity depth (after print test) | 6 (`holder_sleeve_extra_d`) |
| Derived sleeve total depth | 25.04 |
| Cavity depth (above floor) | 22.54 |
| Sleeve back | **closed** — floor is the bottom-out stop |

---

## USB-C panel mount (QIANRENON rectangular, 2× M3 screw, proud flange)

USB-C 3.1 female-to-female 10 Gbps panel mount adapter. Aluminum flange sits proud of the panel front by 3.6 mm; body protrudes 26.4 mm behind.

| | Value |
|---|---|
| Body (through cutout) W × H × D | 17 × 23 × 26.4 |
| Front flange W × H × T | 19 × 36.6 × 3.6 |
| Cutout W × H | 17.4 × 23.4 (per-side clearance 0.2 via `usbc_body_clr`) |
| Screw hole diameter | 3.2 (M3 clearance) |
| Screw hole pitch (vertical) | 30 (`usbc_screw_y_pitch`) |
| Total depth | 30 (flange 3.6 + body 26.4) |

Flange overlaps the panel around the cutout and is retained by 2 M3 screws through the panel.

---

## Big square hole (84.1 × 84.1)

Generic large cutout — purpose TBD. Sharp corners, no rear features.

| | Value |
|---|---|
| Cutout W × H | 84.1 × 84.1 |

---

## Stream Deck Mini (proud-bezel mount, 4 rear corner clips)

**Removed from the aux faceplate after print-test passed.** Design notes saved separately in [`design_notes_streamdeck_mini_pocket.scad`](design_notes_streamdeck_mini_pocket.scad) — re-`include<>` to put it back on a future panel.

| | Value |
|---|---|
| Bezel face W × H | 85.2 × 61.3 |
| Body depth (face → back, excludes stand) | 17 |
| Integrated rear stand depth | 41 (total 58 from face) |
| Bezel corner radius | ~6 |
| Real button-row span (MEASURED) | 54 × 34.7 |
| Cutout extra clearance (locked after testing) | 1.0 per side |
| **Final cutout** | 56 × 36.7, r=3 |
| Corner clip arm | 2.5 (X) × 8 (Y) × (sd_d + hook_h) tall |
| Corner clip hook engagement | 1.2 (= hook_d 1.5 − clip_gap 0.3) |

The cutout exposes only the button area; the bezel rim (~15.6 / ~13.3 mm per side) is captured behind the panel.

---

## HDMI switch (vertical, rear sleeve, M2 set screws)

QIANRENON-style HDMI switch mounted with its long axis vertical on the **display faceplate** (not the aux faceplate). Press-fit cutout + rear sleeve with 2 M2 clearance holes through L+R walls for set screws clamping the device sides.

| | Value |
|---|---|
| Device W × H × D (in mount orientation) | 11.02 × 75.2 × 17.1 |
| Panel cutout | 11.02 × 75.2 (sharp corners) |
| Sleeve depth (deepened after test) | 35 (`hsw_d`) |
| Sleeve wall thickness | 2.5 |
| M2 set screw axis | Single X-axis cylinder drilled through both L/R sleeve walls |
| M2 hole diameter | 2.4 (M2 clearance) |
| M2 Y position | top of sleeve − 6.6 (from "back" of device in rotated orientation) |
| M2 Z position | sleeve mid-depth (−hsw_d/2) |

---

## Faceplate-attachment mount holes (Stream Deck era — kept in design notes)

Two M3 clearance holes on diagonally-opposite panel corners for attaching the bracket to a faceplate. Currently unused on the aux faceplate (slant-insert holes do the mounting).

| | Value |
|---|---|
| Hole diameter | 3.2 (`fp_mount_d`) |
| Inset from panel corner | 4 (`fp_mount_inset`) |

---

## Horizontal layout chain (current aux faceplate)

Devices auto-positioned left-to-right with `panel_layout_gap = 10` between adjacent device outer footprints (sleeve outer / flange edge / clip outer).

```
CF (-79)  →  HOLDER (-36.35)  →  USB-C (+6.4)  →  BIG HOLE (+67.95)
```

CF X is fixed; downstream centers derive via chain math (each = previous outer + gap + this device half-width + this device wall/clip thickness).

---

*Generated 2026-05-30. Update when a new device joins the project or measurements change.*

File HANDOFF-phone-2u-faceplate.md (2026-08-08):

# Console10 Phone Dock Faceplate — 2U, Pixel 10 Pro XL (v0.2, 2026-08-08)

Source: `C:\Users\john_\dev\Console10\Console10_phone_2u_faceplate.scad`
STLs:   `C:\Users\john_\dev\Console10\stl\Console10_phone_2u_panel.stl`
        `C:\Users\john_\dev\Console10\stl\Console10_phone_2u_lever.stl`
        `C:\Users\john_\dev\Console10\stl\Console10_phone_2u_ejector.stl`

2U (253 x 88.9 x t3) slant faceplate holding the CASED Pixel 10 Pro XL
landscape in a recessed pocket, wireless charger puck flush in the floor
(magnetic hold), and an airlock-style pull-down lever that ejects the phone
off the magnets. Blender demo scene:
`...\scratchpad\phone_eject_demo.blend` (session temp — re-buildable from
`build_eject_anim.py` pattern; kinematics below).

## Key dimensions (all measured, no guesses)

- Phone WITH case (John, 2026-08-08): 169 x 81 (81.6 at buttons) x 11.4;
  camera bump 13.62 thick, 26.4 wide. Bump position NOT measured
  → both floor ends relieved 36 mm (`cam_end_relief_w` [TODO-verify]).
- Pocket: 170 x 82.6 x 12.4 deep (0.5 clearance/side; buttons govern height).
  Bare phone fits looser/deeper — intended.
- Charger puck (from PixelTabletFrame `charger_puck.scad`): D60.1 x 8.9,
  bore D60.6 through the floor, friction boss behind (`puck_clr` 0.25/side).
- Mount: cheek slant inserts, wide pair `mount_y = [6.35, 82.55]`, Φ5.5.
  **Panel mounts at slant s = 133.35** (above the 3U macropad panel; holes
  land on the 139.70 / 215.90 rows). At s=0 the 6.35 row has no hole
  (front gap) — use [50.80, 82.55] instead.

## Eject mechanism

Lever on the right wing rides an M3 x 35 axle (+ nyloc — nylon-insert lock
nut so lever action can't back it off; leave it snug-not-tight) in two lugs
behind the plate. L-handle: arm through a rounded track slot, 26 mm grip bar
reaching OUTBOARD (never overlaps the phone), knurled knob, parked 45° up /
pulled 45° down (90° throw). `handle_R = 37` puts the knob ~1.5 mm off the
face at both ends of travel.

Crank disc on the hub carries a D5 pin at R = 7.62 that drives a slotted
boss (close-fit in push direction, elongated +y for the arc) on a stem
routing UNDER the tub end wall to the ejector plate behind the RIGHT relief
window. Plate parks 2.62 below the floor plane (camera bump clears → phone
stays reversible); travel = 2.62 dead + 5.0 push. dz = 7.62·(1 − cos θ).
Pushing the lever back up positively retracts the plate.

## Print & assembly

- `part="panel"` — face-down, no supports.
- `part="lever"` — as exported (bores vertical), no supports.
- `part="ejector"` — face-down; SUPPORT the stem+boss beam (~30 mm
  cantilever ~8 mm up).
- Pose the assembly in the GUI with `LEVER_ANGLE = 0..90`;
  `part="assembly"`, mocks via `show_phone` / `show_puck`.

## First-assembly tune points (single constants at top of file)

- Boss slot pin clearance: +0.6 on `pin_d` — the load-bearing fit.
- Stem-under-wall gap: 0.5 in `stem_top0`.
- Puck friction: `puck_clr = 0.25`.

## TODO v0.3

- Detent/latch at the locked position (magnet or bump) so the lever
  doesn't flop.
- Puck retention nubs if friction ring is loose.
- Verify camera-bar offset ≤ 36 mm from the phone end (with case).
- Cosmetic: raised bezel around the lever slot (airlock-panel look).

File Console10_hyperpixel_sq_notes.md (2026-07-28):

# Console10 — HyperPixel 4.0 Square Faceplate — Working Notes

**Status:** v0.1 frame built & validated (manifold). **Dimensions CONFIRMED 2026-06-11** from the Pimoroni mechanical drawing — window tightened to **73** (0.5 mm reveal/side) and an **active offset** applied for the asymmetric bezel. The "holes under glass" catch is now visually proven (`preview/hp_sq_holes.png`). Retention (v0.2) is the only design work left; it needs a **rim caliper + a photo of the board BACK** (and the board's mounting orientation locked).
**Started:** 2026-06-11
**File:** `Console10_hyperpixel_sq_faceplate.scad`
**Previews:** `preview/hp_sq_iso.png`, `preview/hp_sq_front.png`, `preview/hp_sq_rear.png`
**STL check:** `preview/hp_sq.stl` — `Simple: yes` (manifold/printable)

---

## 1. What we're building

A Console10 3U faceplate for the **Pimoroni HyperPixel 4.0 Square *Touch*** (720×720 IPS,
capacitive). Same family as `Console10_display_faceplate.scad` / `Console10_lcd_simple_faceplate.scad`:
a uniform **3 mm flat plate** that bolts to the cheek **slant inserts**, screen behind the front face.

**Decisions locked (with John):**

| Decision | Choice |
|---|---|
| Variant | Square 4.0 **Touch** (board 84×84×9.5 mm, active ~72×72) |
| Orientation | n/a (square) |
| Pi | **Off-panel**, connected by ribbon — plate holds the **display only**, no Pi bracket |
| Retention | **Front pocket + lip**; screen held by its **own mounting holes** (pattern TBD — see §4) |
| Panel height | **3U** (133.35 mm) |

Nice tie-in: the project already had an **84.1 × 84.1 "purpose-TBD" cutout** in
`Console10_interface_specs.md` and `Console10_lcd_simple_faceplate.scad` (= board + 0.1 mm).
This display was the intended occupant.

---

## 2. What v0.1 contains (the frame)

Modeled on the display-faceplate pattern. Local frame: X = width, Y = up the plate
(= up the slant), Z = thickness; **front face at Z = plate_t (3), back at Z = 0.**

- **3 mm flat 3U slab**, 253 mm wide (sides flush with cheek outer faces ±126.5).
- **Slant-insert mount holes** — 4× Ø5.5 (10‑32 clearance) at **X = ±121.5**, **Y = [50.80, 127.00]**.
  Same pair the LCD/display faceplates use; lands on real cheek rail holes.
- **Recessed front pocket** (84.6 mm) the board drops into **from the back**.
- **Front lip** (1.5 mm thick) framing the active area, overlapping the ~6 mm black bezel margin
  to capture the glass. Glass ends up recessed ~1.5 mm behind the panel front.
- **74 mm viewing window** through the lip (frames the ~72 mm active with ~1 mm bezel reveal/side;
  lip inner edge clears the active area by ~1 mm).
- **Rear locating collar** — open square tube behind the plate, **6 mm deep, 2.5 mm wall**
  (outer 89.6) — locates the board edges and will host retention in v0.2.

### Current parameters (all in the `.scad`)

| Param | Value | Note |
|---|---|---|
| `plate_t` | 3 | uniform panel thickness |
| `n_u` / `plate_h` | 3 / 133.35 | 3U |
| `hp_board` | 84.0 | board W=H — **VERIFY** |
| `hp_active` | 72.0 | active W=H, centered — **VERIFY** |
| `hp_depth` | 9.5 | glass front → back of header — **VERIFY** |
| `hp_rim_t` | 2.6 | glass+PCB rim under the lip — **MEASURE** |
| `board_clr` | 0.3 | per-side, board into pocket |
| `pocket` | 84.6 | = hp_board + 2·board_clr |
| `win_reveal` | 1.0 | bezel reveal around active |
| `window` | 74.0 | = hp_active + 2·win_reveal |
| `lip_t` | 1.5 | front frame thickness / glass recess |
| `collar_h` / `collar_wall` | 6 / 2.5 | rear locating collar |

---

## 3. THE design catch — why retention isn't front-bolted

**CONFIRMED (Pimoroni drawing).** The 58 × 49 HAT pattern's upper-left hole is at (4.0, 6.5)
from the board top-left. In board-centered coords that puts the holes at **x ∈ {−38, +20},
y ∈ {+35.5, −13.5}** — so the **right-hand column (x = +20) is inside the 72 active glass**,
and the left column (x = −38) sits in the ~6 mm left bezel (≈2 mm off the active edge, one side
only). Either way the screen **cannot be front-bolted** with a usable pattern. Proven visually by
the red markers in `preview/hp_sq_holes.png` (render with `-D show_holes=true`).

Retention must come from the **rear** — the locating collar + clips, or a rear clamp frame.

---

## 4. Measurements — mostly obtained (Pimoroni drawing, 2026-06-11)

DONE (from the official drawing): ✅ board 84×84×9.5 · ✅ active 72×72 · ✅ HAT pattern
58×49, upper-left at (4.0, 6.5) · ✅ bezel ~5.5 L/R, 4.5 top, 6.5 bottom (→ active offset).

Still wanted before cutting a final panel (all marked `[CAL]` in the `.scad`):

1. **Rim thickness** at the edge — glass + PCB the lip/clips bear on (assumed 2.6 mm). Drives
   clip-hook engagement and the glass recess.
2. **M2.5** standoff/screw confirm (only from a forum reply, not the datasheet).
3. **Active offset** — caliper the real top/bottom bezel to confirm the ~1 mm shift and its
   direction; the window currently assumes **header-up**.
4. **Photo of the board BACK** — to place clips/clamp that clear the GPIO header (top, protrudes
   ~8.5 mm) + the FPC/touch connector. Gates the retention geometry.

---

## 5. Next steps (v0.2 — retention)

- **Option A (recommended, screwless):** 4 rear **corner clips** on the locating collar that hook
  the board's back edge — reuses the proven Stream Deck Mini clip pattern
  (`design_notes_streamdeck_mini_pocket.scad`). Hook engagement set from `hp_rim_t`. Prints with
  the plate, no fasteners. **Can be modeled before measuring the holes** (only needs rim thickness).
- **Option B (screwed):** rear **standoff bosses** at the measured mounting-hole pattern, M2.5 from
  behind — only viable if the holes sit in the bezel margin (not under the glass). Needs §4.3.
- After retention: print a **first-article frame**, fit-test the pocket/lip/clip clearances, then
  fold into `designdoc.md` (parts table + changelog) and the README.

---

## 6. How to pick this up (render loop)

```
cd C:\Users\john_\dev\Console10

# iso
"C:\Program Files\OpenSCAD\openscad.exe" -o preview/hp_sq_iso.png ^
  --imgsize=1100,820 --viewall --autocenter ^
  --camera=0,0,0,55,0,25,520 --colorscheme=Tomorrow ^
  Console10_hyperpixel_sq_faceplate.scad

# front (ortho)
"C:\Program Files\OpenSCAD\openscad.exe" -o preview/hp_sq_front.png ^
  --imgsize=900,900 --viewall --autocenter --projection=ortho ^
  --camera=0,0,0,0,0,0,520 --colorscheme=Tomorrow ^
  Console10_hyperpixel_sq_faceplate.scad

# rear (collar), hide the mock screen
"C:\Program Files\OpenSCAD\openscad.exe" -o preview/hp_sq_rear.png ^
  --imgsize=1100,820 --viewall --autocenter ^
  --camera=0,0,0,235,0,25,520 --colorscheme=Tomorrow ^
  -D "show_screen=false" Console10_hyperpixel_sq_faceplate.scad

# STL + manifold check (look for "Simple: yes")
"C:\Program Files\OpenSCAD\openscad.exe" -o preview/hp_sq.stl ^
  -D "show_screen=false" Console10_hyperpixel_sq_faceplate.scad
```

Flags in the `.scad`: `show_screen` (mock display on/off), `show_on_slant` (tilt onto the 30° slant).

---

*Memory: `console10-hyperpixel-sq-faceplate` in MEMORY.md.*

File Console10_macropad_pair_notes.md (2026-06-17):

# Console10 — Twin-MacroPad Lower Panel (notes)

Source: `Console10_macropad_pair_faceplate.scad` (v0.2). The 3U panel beneath the
display, carrying **two Adafruit MacroPad RP2040s** (rotated 90°, PCB-to-PCB at
centre) plus a **row of guarded toggle switches** in the lower skirt.

## Parts to print
| Part | `part=` | STL | Qty |
|---|---|---|---|
| Panel / faceplate | `panel` (default) | `Console10_macropad_pair_panel.stl` | 1 |
| MacroPad mount board (backplate) | `mount_board` | `Console10_macropad_mount_board.stl` | 1 |
| 3-gang switch guard (fused) | `guard_bank` | `Console10_guard_bank3.stl` | **2** |

Export the panel with `show_devices=false show_backplate=false` (geometry only).

## MacroPads
- Two pads, each rotated 90°; boards butt at centre (`mp_gap=0`), OLED/encoder ends
  out at the far left/right. Pads pushed to the TOP (`mp_cy`), blank skirt below.
- Face openings cut flush to the PCB edge (no front lip) so keycaps + OLED clear.
- Retention: rear **mount board** spanning both pads — bolts down onto 8 panel posts
  (±`mp_post_sx` × ±`mp_post_sy` per pad), standoffs up to each MacroPad's 4 PCB holes.

## Guarded switches (v0.2)
- **6 toggle switches**, body **14.7 × 29.1 × 26.8 deep** (behind the panel),
  bushing through a **12.4 mm** hole.
- Row at **Y = 42**; X at **[−80, −52, −24, 24, 52, 80]** — chosen to sit in the
  GAPS between the mount-board posts (posts at X = ±8.07, ±96.07) so each switch
  body clears every post by ≥4 mm and fouls **only the flat mount board**.
- The mount board has a **clearance relief** (`sw_board_relief`) at each switch X so
  the bodies pass through it.
- **OLED status display removed** in v0.2 (was under the left pad).

## Switch guards — fused gangs (the "shuttle" look)
- The printed guard is `space-shuttle-switch-guard.stl` (base 25 × 25, 30 tall).
  Hole axis = guard Y; mounted via `guard_rx=90` (hole → panel normal) + `guard_rz=90`
  (cage reads vertical). At the 28 mm switch pitch the vertical cages overlap.
- `guard_bank(3)` **unions 3 guards into one part** (cages fuse) — printed once per
  trio. Both trios are identical → print the one STL twice.
- Panel seats each gang in a **sharp-cornered locating pocket** (`gang_recess`):
  **86 × 25 mm + 0.5 mm clearance, 2.5 mm deep**, centred at X = ±52, Y = 42, with
  the 3 bushing holes inside. (Plate is 3 mm thick → 2.5 mm pocket leaves 0.5 mm
  backing; thicken locally if a deeper pocket is needed.)

## Key tunables
`tog_x` (switch X list), `tog_cy` (row Y), `gang_w/gang_h/gang_clr/gang_recess_d`
(pocket), `guard_rx/guard_rz/guard_z` (guard orientation), `sw_body_*` (switch
body fit-check), `mp_post_sx/sy` (mount-board posts).

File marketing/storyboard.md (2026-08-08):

# CONSOLE10 — ANNOUNCEMENT FILM: STORYBOARD & SHOT PROMPTS

*Generated 2026-07-30 from `C:\Users\john_\dev\Console10\video_brief.md` v2.0.*
*This file is the shot-numbering source of truth. Before this existed, the shot numbers*
*in `C:\Users\john_\dev\Console10\wip\_RESTART.md` referred to a board that lived only in*
*a chat session and was never written to disk.*

## Revision 2026-07-30 — contradiction pass

Backup of the previous version: `C:\Users\john_\dev\Console10\wip\_storyboard_prefix.md.bak`
(SHA-256 prefix `22857A50FBAA15A6`). Full reasoning:
`C:\Users\john_\dev\Console10\wip\_storyboard_review.md`.

**Applied — mechanical, no creative content changed:**

| # | Was | Now |
|---|---|---|
| Section B beat markers | drifted ~4 s throughout; beats 6+7 read `01:28–01:28` (zero seconds) | re-timed to section C, the timing authority |
| Section C totals | "9 Blender shots = 58 s" | "8 Blender + 1 undecided" — the old line counted shot 09 as Blender while the same row marks it Open |
| Section D header | "supplied for all eleven shot numbers" | "nine of the eleven", with the two deliberate omissions named |
| Shot 05 overlay | 00:40–00:45, claimed to sit over the hold | 00:41–00:43; the hold is only 00:41.2–00:42.6 |
| Shot 08 | screen / keypad / blank, guards unmentioned | guarded toggle row required in frame; MacroPad state 2.5 s → 3.0 s |
| Shot 11 camera | three incompatible specs across fields 4, 5 and J | standardised on az −118°, `--framing 0` — matches the rendered asset |
| Shot 11 status | unrendered | ✅ rendered, `C:\Users\john_\dev\Console10\wip\_anim_shot11.mp4` |
| Section G SFX | "twelve soft ticks in 07" | twelve in 07a **and** twelve in 07b (predated the split) |
| Section H | shot 04 spanned 7 s while called "full 8 s"; 1.5 s gap; summed to 29.5 s | re-cut to sum to exactly 30.0 s |
| Section I Hook C | "footprint matches almost exactly" against A4 — **false** | replaced with the 19-inch width comparison; the measurements are recorded in place |
| Section J risk 3 | "unresolved" camera solve | marked **resolved**, with the verified 1.202 m figure |
| Section J guarded switches | recommended cutting the VO line | recommendation **withdrawn** — the switches were already on screen |

## Revision 2026-07-30b — the part count

John: *"the core product is 4 parts. The top, bottom and two cheeks/sides."*

**The film said five. The product is four.** The front slant insert is optional and is not a
cabinet part. Every "five" is now "four": section A, beat 2, the section C row and overlay,
and shot 05 fields 4, 5, 7, 8, 9, 10 and 12.

**Shot 05 was re-rendered 2026-07-30 and now shows four.** `C:\Users\john_\dev\Console10\wip\_anim_shot05.mp4`
previously showed five bodies against a VO that says four; the log now reads `keyframed 4 parts`
and the asset is 1.71 MB. Measured consequences (model validated against the logged 5-part
envelope before the re-render, which is why these numbers were trusted):

| | 5-part (superseded) | 4-part (on disk now) |
|---|---|---|
| Seated envelope | 253.0 × 228.6 × 217.4 mm | **unchanged** |
| Exploded envelope | 531.3 × 383.3 × 494.8 mm | 531.3 × **245.2** × 494.8 mm |
| Camera | 2.441 m | **2.278 m** |

**Shots 04, 07a, 07b and 11 are unaffected** — they frame on the seated envelope, which does
not change. Only shot 05 needed re-rendering, and it was, on 2026-07-30.

**The hold was NOT lengthened.** This paragraph originally said the hold was "being
lengthened to frames 77–137 at the same time since the re-render is mandatory anyway". That
never happened: the `--reseat` cycle fractions live inside `_anim_strip.py` (0.40 and 0.58
of the frame count) and were not changed, so the rendered asset holds **frames 77–111**, as
it always did. Corrected 2026-08-01 to match what is on disk. Lengthening the hold is still
available as an option — it needs the fractions parameterised and a ~4 min re-render — but
it is a choice, not a completed change.

Second-order finding, recorded in section J: this is the **second** optional part to be
counted as a cabinet part, after the slant cap. The root cause is that nothing in the export
path distinguishes cabinet from accessory. `C:\Users\john_\dev\Console10\designdoc.md` §1
also said five and was wrong at source — flagged but not edited for two sessions, because
that is the product authority and John's file. **Corrected 2026-08-01 on his instruction**,
along with six other live instances. See section J.

**Flagged, deliberately NOT applied — these are yours to call:**

1. **Narration pacing.** Beat 3 runs at 4.09 w/s against a 2.22 w/s film average, and it is
   the structural argument. Beat 1 runs at 1.03 w/s. It rebalances inside 88 s. See the
   pacing warning in section B.
2. ~~"Five printed parts" vs the optional front insert.~~ **CLOSED.** Resolved by John — it
   is four — and shot 05 was re-rendered 2026-07-30 (log: `keyframed 4 parts`).
3. **Shot 11's 5-second hold**, which section J already calls the weakest editorial choice.
4. **Shot 09's source** — the standing judgement call. Still open.
5. ~~`designdoc.md` L63 still says five printed parts.~~ **CLOSED 2026-08-01.** Corrected at
   source, along with six other live instances across `README.md`, this file and
   `wip\_RESTART.md`. See section J.

*List re-checked 2026-08-01. Only items 1, 3 and 4 remain open — all three are editorial
judgement calls for John, not work waiting on anyone.*

## Provenance note — why eleven shots, not eight or nine

The brief contradicts itself on shot count. Section D and the `<veo_technique>` block say
"8 or 9 shots… not 11". Section E ("all **eleven** VEO PROMPT fields"), section J
("continuity risk across the **eleven** shots") and `<working_agreements>` ("**Eleven**
shots at twelve fields each is already long") all say eleven. Three to two for eleven, and
the 8–9 figure reads as a later measured insert that was never propagated to the other
sections.

The 8–9 arithmetic also rests on a premise that no longer holds. It divides 75–90 s by
Veo's fixed ~10 s clip. But the standing decision is that product shots come from Blender,
and the brief itself says "Blender shots can be any length you specify, so use them to trim
the total". With three Veo shots at 10 s and eight Blender shots averaging ~7 s, eleven
shots total **88 s** — inside the target. The constraint dissolves rather than binds.

Keeping eleven also preserves the 192 frames already rendered as
`C:\Users\john_\dev\Console10\wip\anim\shot05_0001.png` … `shot05_0192.png` and the cut at
`C:\Users\john_\dev\Console10\wip\_anim_shot05.mp4`. Renumbering would have invalidated a
finished asset to satisfy a line the brief had already half-retracted.

**Flagged as instructed:** the brief is mistaken in section D. Proceeding with eleven as
written elsewhere.

---

## A. CREATIVE CONCEPT

Console10 is a rack that stopped pretending to be furniture. The film earns its credibility
the way the object does — by showing the joint, not the silhouette. It opens in the honest
mess of a home lab, where good equipment sits on a desk in a pile because the only
alternative is a nineteen-inch cabinet built for a room nobody has at home. Then it cuts to
a controlled studio and simply looks at the thing: a raked, trapezoid-sided cabinet the
width of a sheet of paper, and the four printed parts it comes apart into. The middle of the
film is structural argument rather than montage — the cheek edge *is* the mounting surface,
the rake and the rear plane are both real 4U planes, a rack ear bolts to printed plastic and
the bolt goes somewhere. It closes on a desk at dusk with the machine doing quiet work, and
on the only community claim that is true today: the files are public, the licence is MIT,
and the door is open. No crowd, no ecosystem, no numbers. The tone throughout is a competent
engineer showing you their work — warm, unhurried, and specific enough that an enthusiast
can check it.

---

## B. NARRATION SCRIPT

*Timed to 88 seconds. Recorded in post — never generated. Beat markers in brackets.*

*Beat markers re-timed 2026-07-30 to match section C, which is the timing authority.
They had drifted ~4 s throughout and beats 6+7 read "01:28–01:28" — zero seconds for
the closing VO. Section C sums to exactly 88 s and section G's music cues already
agreed with it, so B was the lone outlier.*

> **Pacing warning — unresolved, needs a decision.** Word counts against the picture
> time section C allocates: beat 1 = 31 words in 30 s (1.03 w/s), beat 2 = 53 words
> in 16 s (3.31 w/s), beat 3 = **45 words in 11 s (4.09 w/s)**, beat 4 = 38 in 18
> (2.11), beat 5 = 13 in 8 (1.62), beats 6+7 = 15 in 5 (3.00). The film averages
> 2.22 w/s, which suits the "warm, unhurried" tone. **Beat 3 runs at nearly double
> that, and beat 3 is the structural argument — the panels *are* the rails, ears bolt
> into 10 mm of printed wall, two 4U planes. The most credible material in the film is
> delivered fastest, while beat 1 spends 30 s saying "your desk is a mess" in 31 words.**
> At 2.2 w/s, beat 1 needs ~14 s, beat 2 ~24 s, beat 3 ~20 s. Slack in beats 1 and 5 is
> ~18 s; the shortfall in 2 and 3 is ~17 s, so **it rebalances inside 88 s without
> cutting a word or a shot** — trim shots 01–03 from 10 s to 6–7 s each and give the
> recovered time to shots 06 and 08. Not applied here because it changes the shot
> durations in section C and the 30-second cut in section H.

**[Beat 1 — The problem] 00:00–00:30**

> A Pi here. A switch there. A drive enclosure balanced on a book.
> (pause)
> Your equipment is real. Your rack shouldn't be a nineteen-inch cabinet
> built for a room you don't have.

**[Beat 2 — The reveal] 00:30–00:46**

> Console10 is a ten-inch rack in console form.
> About as wide as a sheet of paper. Raked, so the front face works at the angle
> your hands and eyes already want.
> Four printed parts. Two cheeks, a top, a bottom.
> Every one of them prints in a single piece.

**[Beat 3 — The system] 00:46–00:57**

> There is no rail part, because the side panels *are* the rails.
> Equipment bolts its rack ears straight into brass inserts set in ten millimetres
> of printed wall.
> Two mounting planes per module — the thirty-degree front, and the vertical rear.
> Four U on each.

**[Beat 4 — In use] 00:57–01:15**

> Swap the front and you change what the machine is for.
> A screen. A keypad. A row of guarded switches. A blank when you want quiet.
> It sits on a desk, next to the monitor, and it works.

**[Beat 5 — Customisation] 01:15–01:23**

> The source is parametric. Change a number, print the part, bolt it on.

**[Beats 6 & 7 — Open source, identity] 01:23–01:28**

> It's MIT licensed and the files are public.
> Print it. Change it. Make it yours.

*Note on the draft: the supplied draft closed with "built by makers, and ready to grow with
the community", which asserts a community that `<not_yet_true>` rules out. Replaced with
"Print it. Change it. Make it yours." — an invitation rather than a claim, and warmer for
being addressed to one person instead of a crowd.*

---

## C. STORYBOARD TABLE

| # | In–Out | Dur | Beat | Source | Description | Narration fragment | Overlay |
|---|---|---|---|---|---|---|---|
| 01 | 00:00–00:10 | 10s | 1 Problem | Veo | Loose small equipment scattered across a dark desk — a single-board computer, a switch, a drive enclosure on a book. No Console10 in frame. | "A Pi here. A switch there. A drive enclosure balanced on a book." | none |
| 02 | 00:10–00:20 | 10s | 1 Problem | Veo | A full-height nineteen-inch rack standing in a domestic room, absurdly oversized and mostly empty. No Console10 in frame. | "Your equipment is real." | none |
| 03 | 00:20–00:30 | 10s | 1 Problem | Veo | Slow push across the cluttered desk toward a clear empty space, as if the desk is waiting. No Console10 in frame. | "Your rack shouldn't be a nineteen-inch cabinet built for a room you don't have." | none |
| 04 | 00:30–00:38 | 8s | 2 Reveal | **Blender** ✅ | The assembled cabinet, slow 12° arc. First sight of the object. | "Console10 is a ten-inch rack in console form. About as wide as a sheet of paper." | `CONSOLE10` lower third, in at 00:32 |
| 05 | 00:38–00:46 | 8s | 2 Reveal | **Blender** ✅ | The **four** parts separate along their assembly axes, hold, and re-seat. Locked-off camera. | "Four printed parts. Two cheeks, a top, a bottom." | `4 PRINTED PARTS` upper right, 00:41–00:43 |
| 06 | 00:46–00:51 | 5s | 3 System | **Blender** ✅ | Macro on a real Ugreen CM753 1U panel bolting flat to the cheek edge face, screw entering an insert in the 10 mm wall. | "There is no rail part, because the side panels *are* the rails." | none |
| 07a | 00:51–00:54.5 | 3.5s | 3 System | **Blender** ✅ | The twelve front-slant insert positions illuminate bottom to top on both cheeks, then hold. Locked off at the established −118° angle. | "Two mounting planes per module." | `4U FRONT` centre, 00:52.5–00:54.5 |
| 07b | 00:54.5–00:57 | 2.5s | 3 System | **Blender** ✅ | Cut to behind the unit, looking into the open rear bay. The twelve rear-plane positions illuminate bottom to top, then hold. | "Four U on each." | `4U REAR` centre, 00:55.5–00:57 |
| 08 | 00:57–01:05 | 8s | 3→4 System/Use | **Blender** ⚠ | Faceplates exchange on the slant: screen, then the twin MacroPad (guarded toggle row visible in its lower skirt), then blank. | "Swap the front and you change what the machine is for." | none |
| 09 | 01:05–01:15 | 10s | 4 In use | **Open** ⚠ | The unit on a real desk at dusk beside a monitor, screen glowing, small status LEDs alive. | "It sits on a desk, next to the monitor, and it works." | none |
| 10 | 01:15–01:23 | 8s | 5 Custom | **Blender** | Parametric source on screen, a dimension changes, the part regenerates, then the printed part bolts on. | "The source is parametric. Change a number, print the part, bolt it on." | none |
| 11 | 01:23–01:28 | 5s | 6+7 Open/CTA | **Blender** ✅ | Return to the hero framing of 04, held, as overlay resolves. | "It's MIT licensed and the files are public. Print it. Change it. Make it yours." | `CONSOLE10` / `MIT LICENSED` / `github.com/…` stacked centre, in at 01:24 |

**Totals:** 3 Veo shots × 10 s = 30 s. 8 Blender shots = 48 s. 1 undecided (shot 09) = 10 s.
**88 s.** *Corrected 2026-07-30: the previous line read "9 Blender shots = 58 s", which
counted shot 09 as Blender while the same row marks it **Open** and section J recommends
Veo. The total is 88 s either way, but the old wording silently pre-empted an open decision.*

*Shot 07 was split into 07a and 07b on 2026-07-30. The two mounting planes face
in opposite directions, so no single restrained camera can show both — see the
shot 07 notes below. The split costs nothing: 3.5 s + 2.5 s = the 6 s the single
shot was budgeted, and the timeline is unchanged. Twelve rows, eleven shot
numbers.*

**Legend:** ✅ rendered and on disk. ⚠ blocked on geometry that does not exist yet — see
section J. **Open** = source not yet decided (shot 09 is the standing judgement call).

---

## D. SHOT PROMPTS

*Field 11 (VEO PROMPT) is supplied for **nine of the eleven** shot numbers. For the Blender
shots it is a **fallback only** — see the standing decision in section J. Where a Blender
render is the intended source, field 12 states which style_bible clauses do NOT apply to it.*

*The two deliberate omissions are **shot 05** and **shot 10**, and they are omissions rather
than oversights. Shot 05's whole job is counting the cabinet parts, and Veo is measured to
invent an extra panel; shot 10's whole credibility is that the on-screen source code is real,
and a generator asked to render code produces convincing nonsense. Reasoning in section J. Do not "complete
the set" by writing prompts for them.*

### SHOT 01

1. **SHOT** — 01
2. **DURATION** — ~10 s (Veo)
3. **PURPOSE** — Establish the problem physically, without naming it: good equipment living badly.
4. **VISUAL** — A dark desk seen at a low oblique angle. A bare single-board computer sits on its own antistatic bag, a small eight-port switch beside it with cables fanning off the back, and a 2.5-inch drive enclosure balanced on a hardback book to keep it level. Everything is real and working — small green link LEDs blink — and everything is provisional.
5. **CAMERA** — Short telephoto, 20 cm above desk height, a slow 15 cm dolly left to right that lets each object pass through the focal plane in turn.
6. **LIGHTING** — Single large soft key from upper left, late-afternoon quality. Fill weak. Background falls to charcoal. Status LEDs are the only saturated colour.
7. **PRODUCT ACTION** — Nothing moves but the camera and the blinking LEDs. A cable sways very slightly at the start and settles.
8. **NARRATION** — "A Pi here. A switch there. A drive enclosure balanced on a book."
9. **OVERLAY** — none.
10. **SOUND** — Ambient: quiet room tone, a distant fan. SFX: none. Music: nothing yet — the bed enters on shot 02.
11. **VEO PROMPT** — [continuity block from section E verbatim — *note: Console10 is NOT in this shot; use only the final style sentence of the block, not the object description*] Short-telephoto shot twenty centimetres above a dark wooden desk, dollying slowly fifteen centimetres from left to right, shallow depth of field so each object passes through focus in turn. On the desk sit a bare green single-board computer resting on its own antistatic bag, a small eight-port network switch with black cables fanning off its rear, and a small aluminium drive enclosure propped level on a hardback book. Thin green and amber link lights blink on the switch. Large soft key light from the upper left with the quality of late afternoon, weak fill, the background falling away into charcoal. Matte surfaces, real cable weight, cables hanging and bending under their own load. A plain domestic desk with no rack, no cabinet, no printed text, no labels and no visible screens anywhere in frame. Ambient: the quiet room tone of a home office with a distant fan. SFX: none.
12. **GENERATION NOTES** — Text-to-video; no reference stills needed and none should be attached, because Console10 must not appear. No timestamp prompting. **Most likely failure:** Veo tidies the desk into a styled flat-lay and loses the "provisional" read — the drive must look *propped*, not *placed*. If it comes back neat, re-roll with "balanced precariously on a hardback book to keep it level" moved to the front of the subject clause.

### SHOT 02

1. **SHOT** — 02
2. **DURATION** — ~10 s (Veo)
3. **PURPOSE** — Show the wrong answer at full scale, so the right answer needs no argument.
4. **VISUAL** — A full-height nineteen-inch rack cabinet standing against the wall of an ordinary room — carpet, skirting board, a door frame at the edge of shot. It holds one small switch near the top. The rest is empty air behind a mesh door.
5. **CAMERA** — Wide, low, static, slight upward tilt so the cabinet reads as tall. Deep focus.
6. **LIGHTING** — Flat domestic daylight from a window off-left. Deliberately unglamorous — this is the only shot in the film that is not lit like product.
7. **PRODUCT ACTION** — Nothing moves. The stillness is the point.
8. **NARRATION** — "Your equipment is real."
9. **OVERLAY** — none.
10. **SOUND** — Ambient: room tone, slightly hollow. SFX: the low hum of a single fan, too loud for the room. Music: the low sustained pad enters at 00:12.
11. **VEO PROMPT** — Wide static low-angle shot with a slight upward tilt, deep focus, of a tall black nineteen-inch server rack cabinet standing against the wall of an ordinary carpeted domestic room with a skirting board and a door frame visible at the edge of frame. The cabinet is nearly empty: a single small network switch is mounted near the top and the remaining space behind its mesh front door is bare. Flat unglamorous daylight enters from a window off to the left; no studio lighting, no rim light, no atmosphere. The cabinet dwarfs the room around it. A domestic interior with no data centre, no server room, no rows of other cabinets, no printed text, no signage and no labels in frame. Ambient: slightly hollow room tone. SFX: the low continuous hum of one cooling fan.
12. **GENERATION NOTES** — Text-to-video. No reference stills. **Most likely failure:** Veo fills the rack with equipment because "server rack" is a strong prior — the emptiness carries the entire argument. If it returns populated, re-roll with "almost entirely empty, one small switch at the top and nothing else" as the opening clause of the subject description.

### SHOT 03

1. **SHOT** — 03
2. **DURATION** — ~10 s (Veo)
3. **PURPOSE** — Clear the stage. End beat 1 on an empty space the product will occupy.
4. **VISUAL** — Back on the desk from shot 01. The camera pushes slowly past the scattered equipment toward a bare patch of desk beside a monitor — roughly A4-sized, conspicuously empty. The clutter drifts out of focus in the foreground.
5. **CAMERA** — Short telephoto, slow 25 cm push in at desk height, focus racking from the near clutter to the empty space beyond it.
6. **LIGHTING** — As shot 01, but the key has moved: the empty patch is the brightest thing in frame. Background near-black.
7. **PRODUCT ACTION** — Nothing moves. The rack focus does the work.
8. **NARRATION** — "Your rack shouldn't be a nineteen-inch cabinet built for a room you don't have."
9. **OVERLAY** — none.
10. **SOUND** — Ambient: room tone continues from 02. SFX: none. Music: the pad sustains and thins toward 00:29, leaving near-silence into the cut.
11. **VEO PROMPT** — Short-telephoto shot at desk height, pushing slowly twenty-five centimetres forward past scattered small computer equipment toward a bare empty rectangle of dark wooden desk surface beside a monitor, with focus racking from the near clutter to the empty space beyond. The foreground equipment — a small network switch, coiled black cables, a bare circuit board — falls out of focus as the camera passes. The empty patch of desk is roughly the size of a sheet of paper and is the brightest area in the frame. Large soft key light from the upper left, weak fill, the background falling away to near-black. Matte surfaces, real cable weight, shallow depth of field. A plain desk with no rack, no cabinet, no enclosure, no printed text and no labels anywhere in frame. Ambient: quiet home-office room tone. SFX: none.
12. **GENERATION NOTES** — Text-to-video. No reference stills. Continuity: same desk, same light direction, same monitor as shot 01 — attach the shot 01 output frame as a reference if Veo drifts. **Most likely failure:** the "empty space" reads as an accident rather than an invitation, or Veo fills it with an object. If filled, re-roll describing the space as "a deliberately cleared rectangle of bare desk".

### SHOT 04  ✅ RENDERED

1. **SHOT** — 04
2. **DURATION** — 8.0 s (Blender — 192 frames at 24 fps, complete)
3. **PURPOSE** — The reveal. Establish silhouette, rake, isogrid and desk scale in one uninterrupted look.
4. **VISUAL** — The assembled cabinet alone on near-black. The right-trapezoid cheek profile reads immediately: vertical rear edge, 30° raked front, the isogrid lattice sitting in its solid border on the outer face. The open rear equipment plane is visible as the arc passes. Nothing is mounted in it yet — this is the object, not a configuration.
5. **CAMERA** — 70 mm, elevation 16°, a slow 12° arc from azimuth −124° to −112°, framed on the *assembled* bounds (camera solves to 1.202 m, against shot 05's 2.441 m — the seated and exploded bounding radii differ by 2.03×). The arc is centred on −118°, so the midpoint of the move matches shot 05's locked-off angle exactly and the two cut together. Elevation and distance are held; only azimuth moves, so the object cannot change size across the shot.
6. **LIGHTING** — The established three-light rig: low grazing key at 15° elevation / 138° azimuth to rake across the isogrid pockets, cool fill from the right, warm rim behind. World near-black at 0.013.
7. **PRODUCT ACTION** — Nothing moves. All movement is camera. The isogrid shadows shift across the arc, which is the entire reason the key sits so low.
8. **NARRATION** — "Console10 is a ten-inch rack in console form. About as wide as a sheet of paper. Raked, so the front face works at the angle your hands and eyes already want."
9. **OVERLAY** — `CONSOLE10` in Eurostile or similar, lower third, fading in at 00:32 and out at 00:37.
10. **SOUND** — Ambient: studio silence — the room tone drops away entirely at the cut, which is the sonic reveal. SFX: none. Music: a single low tone lands on the cut at 00:30.
11. **VEO PROMPT** — *(fallback only)* [continuity block verbatim] Slow twelve-degree arcing shot on a seventy-millimetre lens, sixteen degrees above a single 3D-printed desktop rack cabinet standing alone on a near-black studio surface. The cabinet's sides are right trapezoids with a vertical rear edge and a front edge raked thirty degrees from vertical; the outer face of each side carries a recessed lattice of equilateral triangles framed by a solid unpocketed border. The rear of the cabinet is fully open. A low grazing key light rakes across the lattice so each pocket throws a defined shadow, a weak cool fill lifts the right side, and a warm rim separates the top edge from the background. Shallow depth of field. An empty studio with no desk clutter, no mounted equipment, no cables, no printed text and no labels in frame. Ambient: complete studio silence.
12. **GENERATION NOTES** — **Blender is the source, and it is rendered.** Built on `C:\Users\john_\dev\Console10\wip\_anim_strip.py`, *not* on `C:\Users\john_\dev\Console10\wip\_assemble.py` — see section J for why that file must not be used. Command: `"C:\Program Files\Blender Foundation\Blender 5.2\blender.exe" --background --python C:\Users\john_\dev\Console10\wip\_anim_strip.py -- --travel 0 --framing 0 --arc 12 --frames 192 --tag shot04`. The style_bible clauses calling for "fine visible 0.2 mm layer lines" and "brass inserts that read as brass" **do not apply** to this render; John has ruled both out for the Blender product images. **The anticipated failure was checked and did not occur:** the concern was that the arc would push the assembled bounds out of frame at the extremes, since the 0.86 pull-in factor fits a bounding *sphere* while the object is a box whose corners swing with azimuth. Frames 1 and 192 were rendered and inspected first — both sit inside frame with margin. The `--framing 0` solve was independently cross-checked: it computes the seated envelope as 253.0 × 228.6 × 217.5 mm, an exact match for `C:\Users\john_\dev\Console10\wip\_explode.log`.

### SHOT 05  ✅ RENDERED (four parts)

> **✅ THE CORE PRODUCT IS FOUR PARTS. RE-RENDERED 2026-07-30 — this shot now shows four.**
> Log: `keyframed 4 parts`, exploded envelope 531.3 × 245.2 × 494.8 mm, camera 2.278 m.
> The paragraphs below are kept as the record of why, not as outstanding work.
>
> John, 2026-07-30: *"the core product is 4 parts. The top, bottom and two cheeks/sides."*
> Preceded by: *"keep in mind the part that goes across the front is optional."*
>
> **The front slant insert is not a cabinet part.** It is optional, in the same category
> as the slant cap. The cabinet is: **two cheeks, a top, a bottom.**
>
> This supersedes an earlier note in this position which treated five as the default and
> four as a variant. That was my inference and it was wrong in emphasis — four is not a
> configuration of the product, it *is* the product. `C:\Users\john_\dev\Console10\designdoc.md`
> L63 ("A module is **five printed parts**… and a front slant insert") was therefore also
> wrong at source. **Corrected 2026-08-01** — designdoc.md §1 now reads "four printed
> parts" with the front slant insert named as an accessory, and README.md's Architecture
> line and Parts-list table were corrected with it. Backups with SHA-256 prefixes are in
> `C:\Users\john_\dev\Console10\wip\_pre0801_*.bak`.
>
> **This was wrong and has been fixed.** `C:\Users\john_\dev\Console10\wip\_anim_shot05.mp4`
> once rendered five bodies against a VO that says four — the identical defect to the slant
> cap leaking in as a sixth body, in the one shot whose entire job is letting the audience
> count. **Re-rendered 2026-07-30**; the log now reads `keyframed 4 parts` and frame 100
> shows four separated bodies.
>
> **The measured consequences, computed from the seated AABBs in**
> `C:\Users\john_\dev\Console10\wip\_probe_parts.txt` **(the model reproduces the logged
> 5-part envelope exactly, which is why these numbers are trusted):**
>
> | | 5-part (the old, wrong asset) | 4-part (what is now on disk) |
> |---|---|---|
> | Seated envelope | 253.0 × 228.6 × 217.4 mm | **unchanged** |
> | Exploded envelope | 531.3 × 383.3 × 494.8 mm | 531.3 × **245.2** × 494.8 mm |
> | Framing radius | 410.5 mm | 383.1 mm |
> | Camera distance | 2.441 m | **2.278 m** (6.7% closer) |
>
> Only the **depth** of the exploded envelope changes, because the front insert was the
> only part travelling toward −Y. The object ends up ~7% larger in frame, which improves
> a composition that was already loose.
>
> **Shots 04, 07a, 07b and 11 are unaffected** — they frame on the *seated* envelope,
> which does not change. No other render is invalidated.
>
> **Method:** gate `front` out the way `slant_cap` was — remove it from `DIRS` in
> `C:\Users\john_\dev\Console10\wip\_anim_strip.py` and
> `C:\Users\john_\dev\Console10\wip\_explode.py`, and add a `show_front`-style exclusion
> so it cannot leak back. Then re-run the shot 05 command. Verify the body count with
> `C:\Users\john_\dev\Console10\wip\_probe_parts.py`, never by eye.
>
> **The front insert is not banished from the film** — it is a real optional part and
> shot 08's slant-filler state is a natural home for it. It simply must not appear in the
> shot that counts the cabinet.

1. **SHOT** — 05
2. **DURATION** — 8.0 s (Blender — 192 frames at 24 fps, complete)
3. **PURPOSE** — Make the part count countable. This is the shot Veo structurally cannot do.
4. **VISUAL** — The assembled cabinet separates into its **four** printed parts, each travelling along the axis it actually assembles along — cheeks laterally, top up, bottom down. The parts hold apart long enough to be counted, then re-seat. Locked-off camera throughout, framed on the fully-exploded envelope so the seated and exploded states share one composition. *The optional front slant insert is excluded: it is not a cabinet part, and this is the shot that counts the cabinet.*
5. **CAMERA** — 70 mm, elevation 16°, azimuth −118°, locked off at **2.278 m** (was 2.441 m with the front insert included; the 4-part exploded envelope is 138.1 mm shallower in Y, so the framing radius drops from 410.5 to 383.1 mm). No camera move — the storyboard beat is the parts, and a move would compete with them.
6. **LIGHTING** — As shot 04. Identical rig, identical exposure, so 04 and 05 cut without a grade shift.
7. **PRODUCT ACTION** — Frames 1–77 separate to full travel (139.2 mm), **77–137 hold, 137–192 re-seat**. Ease-in/out at both ends so it reads as deliberate machinery rather than a linear slide. *Hold extended from 34 frames (1.4 s) to 60 (2.5 s), taken from the re-seat. Travel is unchanged at 139.2 mm — it is derived from the seated footprint (253.0 mm × 0.55), which the front insert never influenced.*
8. **NARRATION** — "Four printed parts. Two cheeks, a top, a bottom. Every one of them prints in a single piece."
9. **OVERLAY** — `4 PRINTED PARTS` upper right, in at **00:41**, out at **00:43.5**. *Two corrections, 2026-07-30. (a) The count is four, not five. (b) The old timing read 00:40–00:45, described as "timed to land during the hold" — but the hold is frames 77–111 of a shot starting at 00:38, i.e. **00:41.2–00:42.6**, so only ~1.4 s of the old 5 s card sat over the hold and the rest ran during the separation and 2.4 s into the re-seat, when the parts are closing and no longer separately countable.* **Hold lengthened to frames 77–137 (2.5 s)**, taken out of the re-seat — 1.4 s is short for counting, and since the re-render is now mandatory anyway this improvement is free. Overlay spans the new hold.
10. **SOUND** — Ambient: studio silence. SFX: **four** soft mechanical seats on the re-assembly, the last landing on the cut. Music: the low tone from 04 sustains.
11. **VEO PROMPT** — *(not applicable — see notes)*
12. **GENERATION NOTES** — ⚠ **SUPERSEDED — the asset on disk is the 5-part version and must not be used.** `C:\Users\john_\dev\Console10\wip\_anim_shot05.mp4` (1.57 MB) and `C:\Users\john_\dev\Console10\wip\anim\shot05_0001.png` … `shot05_0192.png` all show five bodies. **Do not delete them** (project rule: never delete without checking) — but do not cut with them either. Re-render prerequisites: exclude `front` from `DIRS` in `C:\Users\john_\dev\Console10\wip\_anim_strip.py` and `C:\Users\john_\dev\Console10\wip\_explode.py`, extend the hold to frames 77–137, then rebuild with `"C:\Program Files\Blender Foundation\Blender 5.2\blender.exe" --background --python C:\Users\john_\dev\Console10\wip\_anim_strip.py -- --frames 192 --reseat --tag shot05`. Expect the log to report an exploded envelope of **531.3 × 245.2 × 494.8 mm** and a camera at **2.278 m**; if it still says 383.3 / 2.441 the front insert is still loading. **No Veo prompt is supplied deliberately** — measurement on 2026-07-29 established that image seeding fixes silhouette and identity but never fixes part count, and a shot whose entire job is counting cannot be delegated to a generator that invents an extra panel. **Historical failures worth keeping — this shot has now had the wrong part count twice:** first the slant cap leaked in as a sixth body (fixed by gating `show_slant_cap`), now the front insert as a fifth. Both were optional parts that reached the render because nothing distinguished "cabinet" from "accessory" in the export path. **The real fix is upstream:** the SCAD should express that distinction once, so no future shot has to remember it. Verify with `C:\Users\john_\dev\Console10\wip\_probe_parts.py`; never count bodies by eye off a render, because overlapping parts merge visually and that produced a wrong count once already.

### SHOT 06

1. **SHOT** — 06
2. **DURATION** — 5 s (Blender)
3. **PURPOSE** — Prove the central structural claim in one image: the cheek edge *is* the mounting surface, and the screw goes into material.
4. **VISUAL** — Extreme macro on the raked front edge of a cheek. A flanged rack ear sits flat against the 10 mm edge face. An M-series socket-cap screw stands in the ear's slot, aligned with a heat-set insert seated in the printed wall. The screw turns and draws down until the flange pulls flush. The uneven grouped rhythm of the insert column runs away out of focus behind it.
5. **CAMERA** — Macro, locked off, perpendicular to the edge face so the flange-to-face contact is unambiguous. No move — a move here would let the viewer doubt what they saw.
6. **LIGHTING** — Tight grazing key almost parallel to the edge face, so the flange's approach to flush is legible as a closing shadow line. Weak cool fill. Everything beyond 30 mm falls to black.
7. **PRODUCT ACTION** — The screw rotates and descends ~4 mm over 5 s; the shadow gap between flange and cheek face closes to nothing and stops. Nothing else moves.
8. **NARRATION** — "There is no rail part, because the side panels *are* the rails."
9. **OVERLAY** — none. This shot must be believed in-camera, not captioned.
10. **SOUND** — Ambient: studio silence. SFX: the fine ratcheting of a hex driver, four clicks, then the dead stop of a screw seating. Music: pad only.
11. **VEO PROMPT** — *(fallback only)* [continuity block verbatim] Extreme macro locked-off shot, perpendicular to the ten-millimetre-thick raked edge of a matte off-white 3D-printed panel. A small flanged metal bracket rests flat against that edge face, and a dark socket-cap screw in the bracket's slot turns slowly and draws down until the bracket pulls flush against the plastic. A column of small brass threaded inserts sits flush in the edge face behind it, spaced in an uneven grouped rhythm, receding out of focus. A tight grazing key light almost parallel to the edge face makes the closing gap between bracket and panel read as a narrowing shadow line. Everything beyond a few centimetres falls to black. Shallow depth of field, no hands, no tools in frame, no printed text and no labels. Ambient: studio silence. SFX: the fine ratcheting of a hex driver, then a screw seating.
12. **GENERATION NOTES** — ✅ **RENDERED 2026-08-01.** `C:\Users\john_\dev\Console10\wip\_anim_shot06.mp4` — 120 frames, 64 spp, 149 s. Command: `... _anim_macro.py -- --frames 120 --spp 64 --key 4.0 --fill 0.35 --ev 0.0 --mblur 0.7 --tag shot06`.

    **The subject changed, and the change is the point.** This field previously called for a generic flanged L-bracket added to `Console10_module.scad` behind a `show_rack_ear` flag. Both halves of that were wrong.

    *No rack ear exists in the product.* Verified: a literal search for `rack_ear` across `C:\Users\john_\dev\Console10` returns four hits, all prose. Console10's own faceplates bolt straight into the cheek slant inserts — there is no third-party ear anywhere in the system. A bracket built to fill the gap was invented geometry, and it rendered as a blank switch plate on a white wall, because that is what it was.

    *The shot now uses a real panel John owns:* the **Ugreen CM753 10-inch rack mount**, `C:\3d files\mini-rack\Ugreen+2.5GBit+Switch+CM753+10-inch+rack+mount\Ugreen 2.5GBit Switch CM753 10-inch rack mount.stl`. Measured 254.0 × 44.5 × 110.4 mm — 10 inches exactly against Console10's 253, and 1U. He has printed it; there is a sliced `.gcode` beside the STL.

    *It is placed in Blender, not OpenSCAD, and deliberately so.* It is a third-party mesh, and pushing third-party meshes through OpenSCAD booleans is precisely what broke the shot 08 macropad export. Blender does not care about manifoldness and no boolean is needed — only a placement.

    *It bolts through a real EIA pair.* Console10's front slant list contains four pairs exactly 31.75 mm apart — (50.80, 82.55), (95.25, 127.00), (139.70, 171.45), (184.15, 215.90) — which is the standard 1U ear pattern. The panel centres at s = 111.125 with the screw on the upper hole at s = 127.00. Seating was confirmed with a wide diagnostic frame, not by eye.

    **Camera note.** Field 5 says "perpendicular to the edge face". Taken literally the flange lies flat to lens and the closing gap is fully foreshortened — the first test frame did exactly that and the edge was invisible. Rendered at 34° off-normal on a 28° bearing (mostly up-slant), so the insert column recedes past the bracket as field 4 asks.

    **Motion blur is on at 0.70 shutter**, because the script measured the screw spinning at 3.4 frames per apparent hex-socket period. Under 4 frames it strobes. The blur is also simply correct: a screw turning 27° inside a 1/24 s exposure smears on any real camera. The alternative — decoupling spin from the 0.79375 mm thread pitch — would make the pitch a lie to hide an artefact.

    Layer-line and brass style clauses **do not apply**.

### SHOT 07a + 07b  ✅ RENDERED

*One shot in the original board. Split into two on 2026-07-30 because the two
mounting planes face in opposite directions and no single restrained camera can
see both — the reasoning is in field 12 and in section J.*

1. **SHOT** — 07a (front plane) and 07b (rear plane), cut back to back
2. **DURATION** — 07a 3.5 s (84 frames) + 07b 2.5 s (60 frames) = 6.0 s, exactly the budget the single shot had
3. **PURPOSE** — Show that there are two mounting planes and that both are 4U, without a diagram.
4. **VISUAL** — *07a:* the assembled cabinet in three-quarter view; the twelve front-slant insert positions illuminate in sequence bottom to top on both cheeks, then hold. *07b:* cut to behind the unit, looking into the open rear bay; the twelve rear-plane positions do the same. The uneven grouped spacing reads in both — the same rhythm, on two different planes, which is the whole point of showing them consecutively.
5. **CAMERA** — *07a:* 70 mm, elevation 16°, locked off at azimuth −118° and 1.202 m — the established angle, so it cuts against 04 and 05 without a reframe. *07b:* same lens, elevation and distance, azimuth +62°, looking into the open back. A cut, not a move: reaching the rear plane from the front needs roughly 180° of arc, which the style_bible's "motion measured in centimetres, not metres" rules out.
6. **LIGHTING** — As shots 04/05, plus a subtle practical: the illuminating insert markers are the only new light source, warm amber and low-intensity, so the shot stays in the film's palette.
7. **PRODUCT ACTION** — No geometry moves in either shot. *07a:* markers rise bottom to top, staggered 5 frames with a 10-frame rise, all lit by frame 66 of 84, then hold. *07b:* staggered 3 frames with a 6-frame rise, all lit by frame 40 of 60, then hold. Both builds complete at ~75% so the narration and overlay land on a fully-lit hold.
8. **NARRATION** — "Two mounting planes per module. Four U on each."
9. **OVERLAY** — Split with the shots: `4U FRONT` centred over 07a, in at 00:52.5, out at 00:54.5; `4U REAR` centred over 07b, in at 00:55.5, out at 00:57. Each label now lands on the plane it names, which the single combined card could not do.
10. **SOUND** — Ambient: studio silence. SFX: a soft tick per marker, quiet enough to be felt rather than counted. Music: pad lifts slightly under the rear-plane reveal.
11. **VEO PROMPT** — *(fallback only — not recommended)* [continuity block verbatim] Slow eight-degree arcing shot on a seventy-millimetre lens around a matte off-white 3D-printed desktop rack cabinet on a near-black studio surface, moving from a front-biased three-quarter view to one that reveals the open rear. Small brass threaded inserts set into the thirty-degree raked front edge glow warm in sequence from bottom to top, hold, and fade; then the same happens along the vertical rear edge. The inserts sit in an uneven grouped rhythm rather than an even ladder. Low grazing key light rakes the triangular lattice on the outer side faces, weak cool fill, background near-black. Shallow depth of field. An empty studio with no mounted equipment, no cables, no printed text and no labels in frame. Ambient: studio silence.
12. **GENERATION NOTES** — ✅ **RENDERED 2026-07-30 as two shots.** `C:\Users\john_\dev\Console10\wip\_anim_shot07a.mp4` (84f) and `C:\Users\john_\dev\Console10\wip\_anim_shot07b.mp4` (60f). Commands: `... _anim_strip.py -- --travel 0 --framing 0 --markers front --frames 84 --tag shot07a` and `... --markers rear --azimuth 62 --frames 60 --tag shot07b`. The `--markers` implementation is verified: `add_insert_markers()` in `C:\Users\john_\dev\Console10\wip\_anim_strip.py` computes all 48 positions (12 front + 12 rear, per cheek) in the module world frame and asserts every one lies inside the cheek's actual mesh AABB before use. The assertion passes, and the mesh AABB comes back as x −126.5..126.5, y 0.0..228.6, z 6.0..211.5 — an exact match for the SCAD constants, so the world-frame mapping is confirmed. A probe render (`C:\Users\john_\dev\Console10\wip\anim\m07probe_0001.png`) shows the front-plane markers landing precisely on the front slant holes of both cheeks.

    **Why it became two shots — keep this, it is the reason the design is what it is.** The two mounting planes face in opposite directions: the front slant's outward normal points forward and up, the rear plane's points straight back at +Y. From the established camera at azimuth −118° (front-left) the rear plane is on the far side of the object. No 8° arc reveals it; reaching it needs roughly a 180° swing, which contradicts the style_bible's "motion measured in centimetres, not metres". This was predicted from the geometry and then confirmed with a probe render rather than trusted. **Do not "simplify" this back into one shot.** Rendering `--markers both` from a single angle silently hides half the markers and looks fine — which is exactly what the first probe did.

    **Marker look:** the first probe used proud amber spheres and read as vanity-mirror bulbs, wrong for this palette. They are now smaller (3.0 mm) and flattened along the bore axis so they sit *in* the edge face. If they still read as decorative at full size, the next step is lighting the bore recesses rather than adding surface geometry.

    **Do not count the dots by eye** off any of these renders. The count is correct by construction — 24 per plane, asserted against the mesh — and these images are exactly the kind `_RESTART.md` warns against counting, because adjacent markers merge visually at this scale.

    **Known stale:** field 11's Veo fallback prompt still describes the original single-shot 8° arc. It is fallback-only for a shot that is now rendered in Blender, so it has not been rewritten — if it is ever actually needed, split it into two prompts first.

    Positions come from the brief and are corroborated by the SCAD (front, from the front-bottom corner: 50.80 / 66.675 / 82.55 / 95.25 / 111.125 / 127.00 / 139.70 / 155.575 / 171.45 / 184.15 / 200.025 / 215.90 mm; rear, from the floor: 6.35 / 22.225 / 38.10 / 50.80 / 66.675 / 82.55 / 95.25 / 111.125 / 127.00 / 139.70 / 155.575 / 171.45 mm). Drive the markers from those constants, not by eye. Layer-line and brass style clauses **do not apply**. **Most likely failure:** the marker glow blows the pinned 0.00 exposure — meter the emissive intensity against the existing plastic values rather than adding light until it looks right, or 07 will not cut against 04/05.

### SHOT 08

1. **SHOT** — 08
2. **DURATION** — 8 s (Blender)
3. **PURPOSE** — Show that the front is the variable, and that changing it changes the machine's purpose.
4. **VISUAL** — Locked on the raked front plane. A screen faceplate is bolted in place; it lifts away and the **twin MacroPad faceplate** takes its position; that lifts away and a blank filler settles. Each lands flush against the slant, bolts aligned to the insert columns. The cabinet behind never moves. **The MacroPad faceplate carries the row of six guarded toggle switches in its lower skirt, and the shot must show them** — this is the state that delivers the VO's "a row of guarded switches", so the skirt sits inside the frame and is lit well enough for the guards to read as guards rather than as bumps. The printable Space Shuttle-style guards over 12 mm toggle bushings are one of the most distinctive things on the whole faceplate; framing them out would waste them.
5. **CAMERA** — 70 mm, locked off, square-ish to the slant so each faceplate is read on its own terms rather than in perspective.
6. **LIGHTING** — As 04/05, with the screen faceplate carrying a practical: abstract non-textual content, a slowly moving plot, low brightness.
7. **PRODUCT ACTION** — Three faceplate states across 8 s: screen (0–2.5 s), **MacroPad (3–6 s)**, blank (6.5–8 s), with ~0.5 s cross-moves. Faceplates travel along the slant normal so they never intersect the cheeks. *Re-balanced 2026-07-30: the MacroPad state now carries **two** VO items, "A keypad" and "A row of guarded switches", because the guards live on that faceplate. Seven words at the film's 2.2 w/s needs ~3.2 s, and the old 2.5 s window was short for it. The extra 0.5 s comes out of the blank, which carries the shortest line.*
8. **NARRATION** — "Swap the front and you change what the machine is for. A screen. A keypad. A row of guarded switches. A blank when you want quiet."
9. **OVERLAY** — none.
10. **SOUND** — Ambient: studio silence. SFX: a soft seat per faceplate, three in total, spaced to the cuts. Music: pad continues; a light rhythmic element enters at 01:00.
11. **VEO PROMPT** — *(fallback only)* [continuity block verbatim] Locked-off seventy-millimetre shot square to the thirty-degree raked front plane of a matte off-white 3D-printed desktop rack cabinet on a near-black studio surface. A rectangular faceplate carrying a small square display is bolted to the raked plane; it lifts away along the plane's normal and a second faceplate carrying two blocks of mechanical keys takes its place; that lifts away and a plain blank panel settles flush. Each panel seats against the raked face with its fasteners aligned to a column of brass inserts along the panel edge. The cabinet itself never moves. The display shows only an abstract slowly moving plot with no text or characters. Low grazing key light, weak cool fill, near-black background, shallow depth of field. No hands, no printed text, no labels, no logos anywhere in frame. Ambient: studio silence. SFX: three soft mechanical seating sounds.
12. **GENERATION NOTES** — ⚠ **BLOCKED, but not on what this field used to say.**

    **The old diagnosis was wrong.** It read "BLOCKED on asset placement… never been exported as world-position STLs". Placement was never the problem: `C:\Users\john_\dev\Console10\Console10_module.scad` already seats all three faceplates on the slant via `faceplate_on_slant()`, `macropad_pair_on_slant(0)` and `lower_blank_faceplate_on_slant()`. The export wrapper simply never exposed them. Fixed 2026-07-31 — `C:\Users\john_\dev\Console10\wip\_parts_export.scad` now has `display`, `macropad` and `blank` cases calling those same entry points, and all three are named in `ACCESSORY_PARTS`.

    **The real blocker.** The macropad export emits `ERROR: The given mesh is not closed! Unable to convert to CGAL_Nef_Polyhedron` — while still exiting 0 and writing 23.77 MB, so file size is *not* evidence of success. Cause: `devices()` in `Console10_macropad_pair_faceplate.scad` imports two third-party non-watertight STLs — `C:\Users\john_\Downloads\5128 MacroPad RP2040-Assembly.stl` (4.9 MB, imported twice inside an `intersection()`, which is what forces the CGAL conversion) and `C:\3d files\NASA\switch guards\space-shuttle-switch-guard.stl` (1.3 MB, unioned six times). That module's own header calls these "fit-check mocks (not printed)". 285.6 s against 14.1 s for the display faceplate.

    **The fix is to stop asking for the boolean.** Fusing visualisation meshes into one watertight solid is something only *printing* needs; a render does not need a single solid at all. Export `panel()` alone, and load the MacroPad and guard STLs into Blender directly as separate objects. Faster, no CGAL, and each component gets its own material — impossible once fused. **This technique is already proven:** shot 06 places John's Ugreen panel in Blender by matrix, and its AABB came back x −127.0..127.0, exactly the centred 254 mm.

    **Two things still outstanding.** (1) `-D show_devices=false` will *not* work through `p_macropad()`, because `-D` binds only the main file's top-level variables and `_parts_export.scad` reaches the macropad file via `use <>`; that needs optional parameters on `macropad_pair_on_slant()`. (2) No faceplate-swap animation mode exists in any script.

    **Fragility worth knowing:** two of the three assets this shot needs live outside the repo, one of them in `C:\Users\john_\Downloads\` — one cleanup from breaking the build, and not version-controlled.

    Layer-line and brass style clauses **do not apply**. **Most likely failure:** the faceplates are shown *sliding in* rather than bolting on, which `<not_yet_true>` explicitly rules out — almost everything in this project bolts, and the only sliding element is the WIP Gridfinity drawer. Motion must be along the slant normal and must end in a seat, never a slot.

### SHOT 09

1. **SHOT** — 09
2. **DURATION** — ~10 s (source undecided — see notes)
3. **PURPOSE** — Put the object in the world. This is the only shot that answers "what is it like to live with?"
4. **VISUAL** — The unit on a real desk at dusk, beside a monitor. Warm window light failing on one side, the mounted screen faceplate and a scatter of small amber and green status LEDs carrying the other. Cables leave the open rear plane and fall behind the desk with real weight. A mug, a notebook — the desk is used, not styled.
5. **CAMERA** — Short telephoto, slow 20 cm dolly in at desk height, shallow depth of field, focus landing on the raked face.
6. **LIGHTING** — The only shot lit as environment rather than product: motivated window light going cold and low, practicals doing the rest. This is deliberately the warmest frame in the film.
7. **PRODUCT ACTION** — Nothing moves but the screen content and the LEDs. A cable sways once and settles.
8. **NARRATION** — "It sits on a desk, next to the monitor, and it works."
9. **OVERLAY** — none.
10. **SOUND** — Ambient: evening room tone, a little traffic through glass. SFX: the single soft click of a relay or a key. Music: the rhythmic element resolves; the pad opens up.
11. **VEO PROMPT** — [continuity block verbatim] Short-telephoto shot at desk height, dollying slowly twenty centimetres toward a matte off-white 3D-printed desktop rack cabinet standing on a used wooden desk beside a computer monitor at dusk. The cabinet's sides are right trapezoids with a vertical rear edge and a thirty-degree raked front carrying a small square display showing an abstract slowly moving plot. Small amber and green indicator lights glow along the mounted equipment. Black cables leave the open rear of the cabinet and fall behind the desk under their own weight. Cold blue window light fails from the left; the display and the indicator lights are the warm sources. A mug and an open notebook sit nearby. Shallow depth of field with focus landing on the raked face. A lived-in home office with no data centre, no server racks, no printed text, no labels and no readable characters on any screen. Ambient: evening room tone with faint traffic through glass. SFX: one soft relay click.
12. **GENERATION NOTES** — ⚠ **THE OPEN JUDGEMENT CALL.** This shot is both a product shot and an atmosphere shot, and the standing decision splits on exactly that seam: product shots come from Blender because Veo cannot hold part count, but atmosphere — dusk light, a used desk, a room — is what Veo is genuinely good at and what Blender would cost days to fake. **My recommendation: seed Veo heavily and accept it.** The part-count risk is low here because the cabinet is largely occluded by mounted equipment and shot at a scale where nobody counts panels; the atmosphere risk in Blender is high. Attach two stills per the ingredients method. If it comes back with an invented extra panel on the visible cheek, fall back to Blender and light a simple desk plane. **Most likely failure:** readable text appears on the mounted display — Veo reliably invents convincing nonsense characters, and this is the only shot with a screen large enough for it to try.
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

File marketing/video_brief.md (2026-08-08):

# CONSOLE10 — ANNOUNCEMENT VIDEO BRIEF v2.0

**Written for:** Claude Opus 5 (the model that will produce the storyboard and shot prompts)
**Video generated in:** Veo 3.1 for shots 01/02/03 only — **everything else is Blender**. See the revision note below.
**Source of truth:** `C:\Users\john_\dev\Console10\designdoc.md` (v3.3, 2026-05-28), `C:\Users\john_\dev\Console10\README.md`, `C:\Users\john_\dev\Console10\Console10_interface_specs.md`

---
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

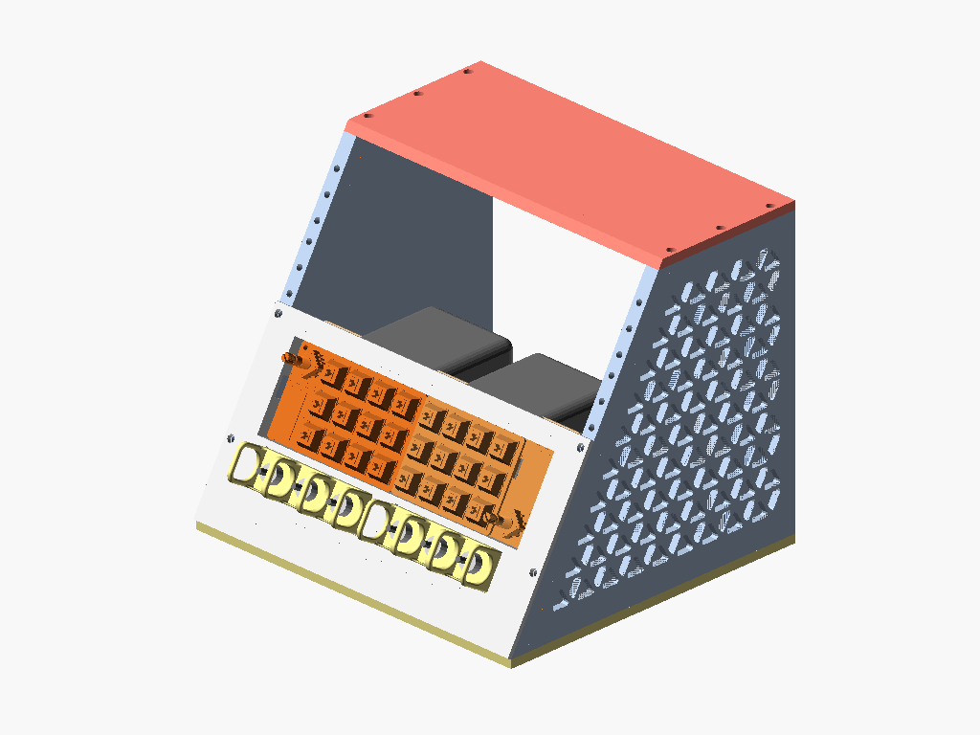
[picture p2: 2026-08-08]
thumbnail.png

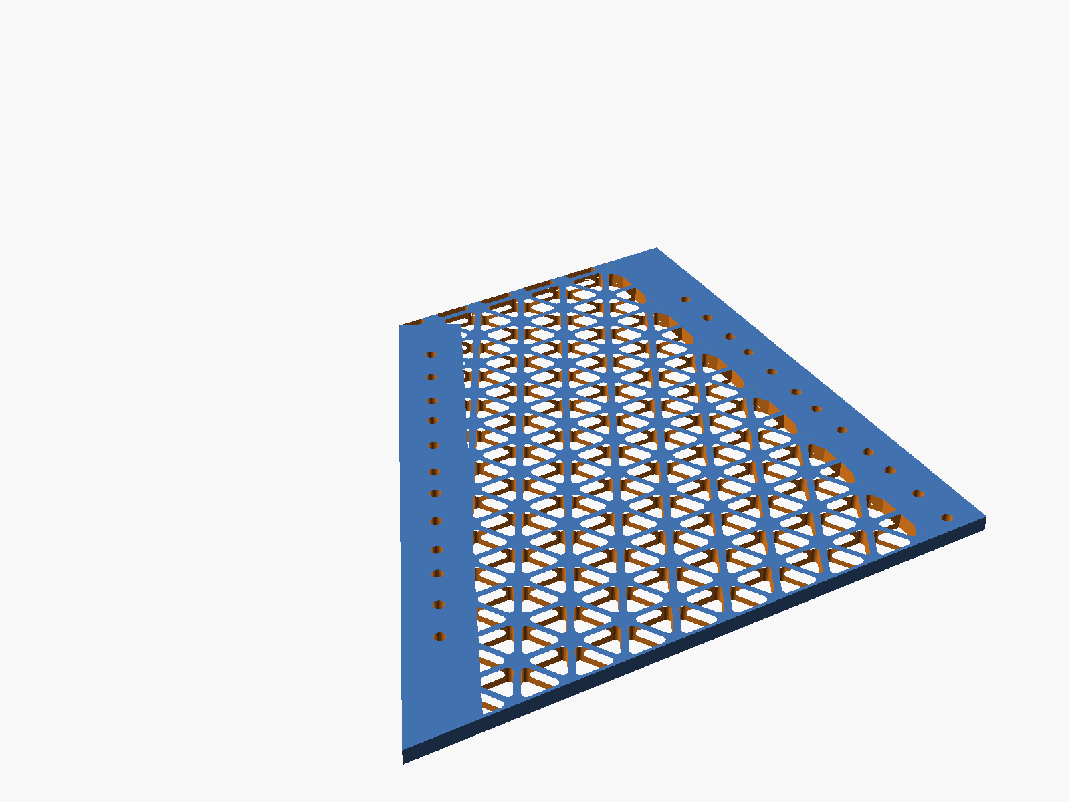
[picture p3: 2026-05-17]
preview/cheek_v22_through.png

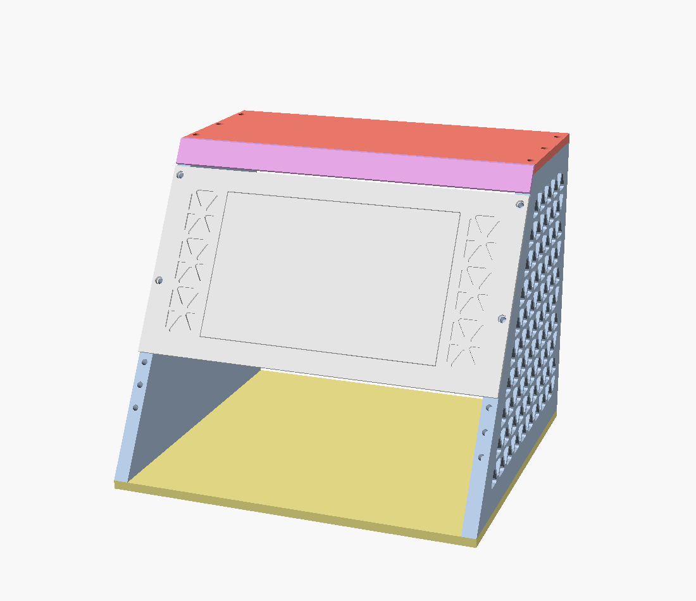
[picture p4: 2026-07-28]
preview/asm_room.png

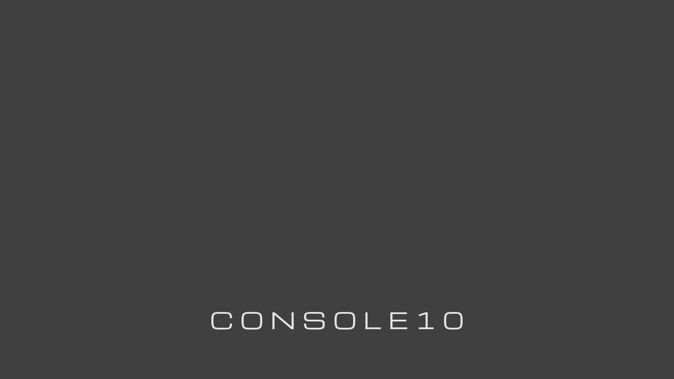
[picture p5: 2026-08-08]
marketing/overlays/overlay_wordmark.png

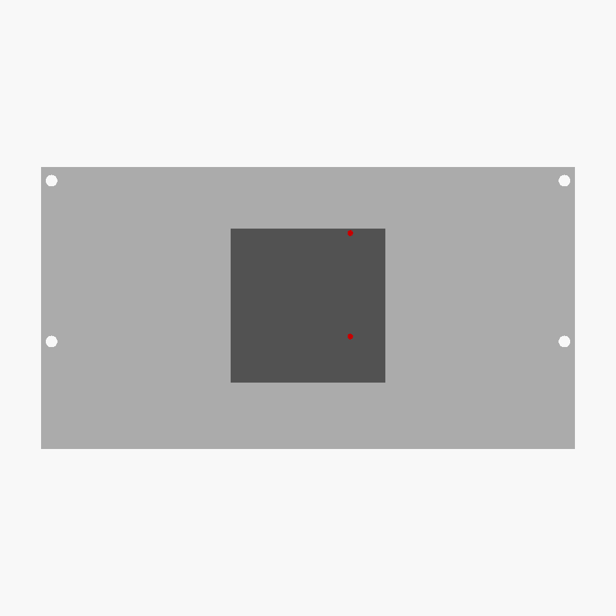
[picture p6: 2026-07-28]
preview/hp_sq_holes.png

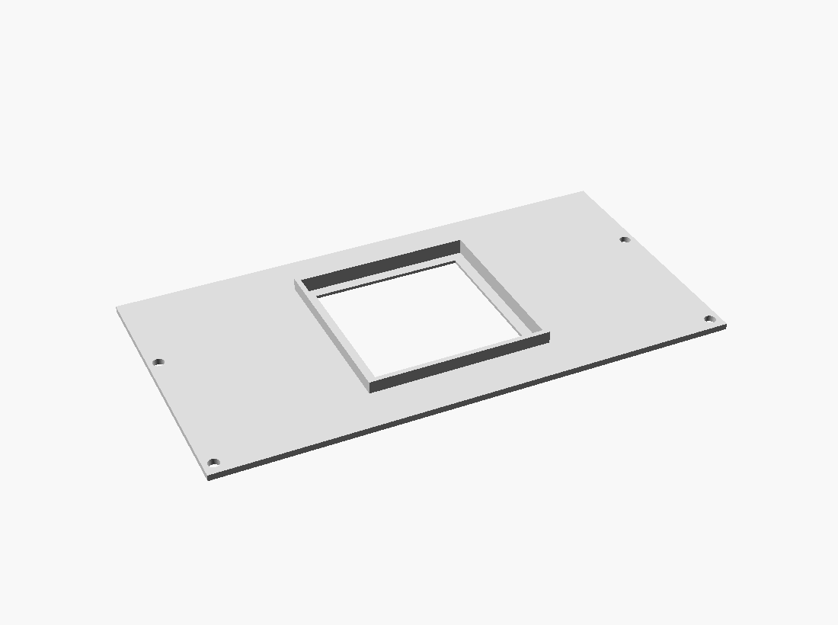
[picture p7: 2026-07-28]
preview/hp_sq_rear.png

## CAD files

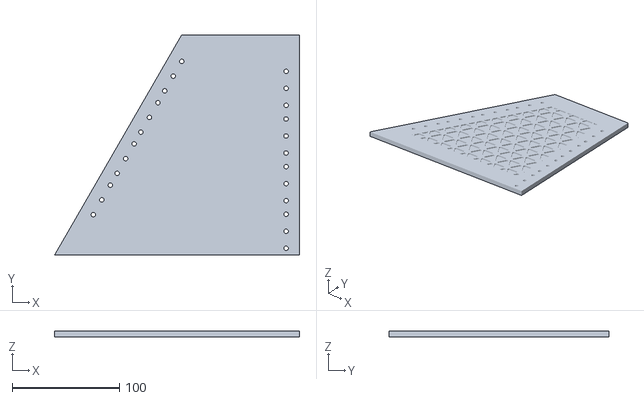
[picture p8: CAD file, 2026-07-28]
Console10_isogrid-do-not-delete.stl
228.6 x 205.5 x 6.00

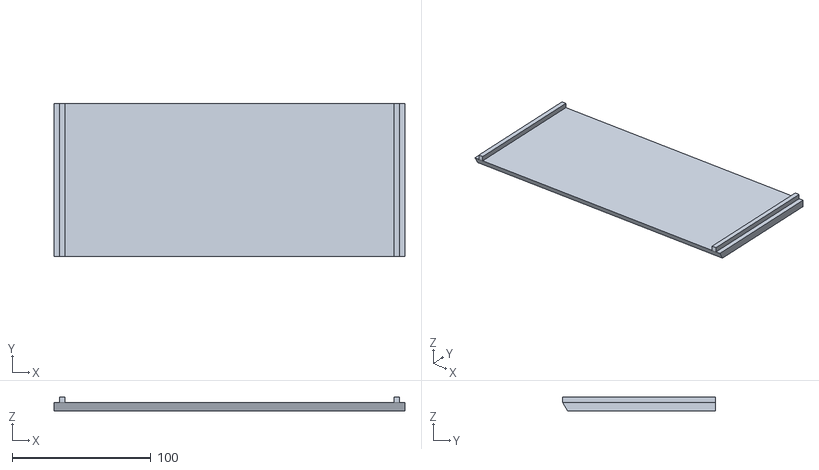
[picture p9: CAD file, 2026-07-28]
preview/top_check.stl
253.0 x 110.0 x 10.0

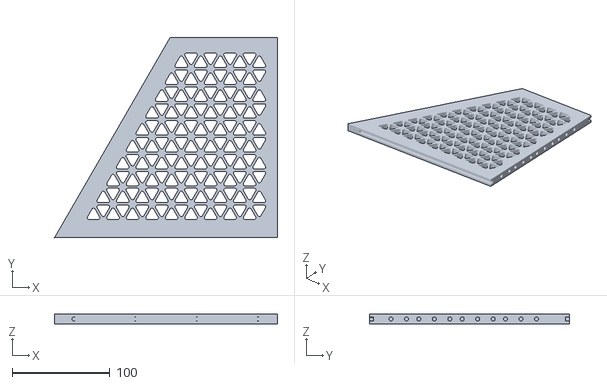
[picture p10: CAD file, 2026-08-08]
stl/Console10_cheek_vent.stl
228.6 x 205.5 x 10.0

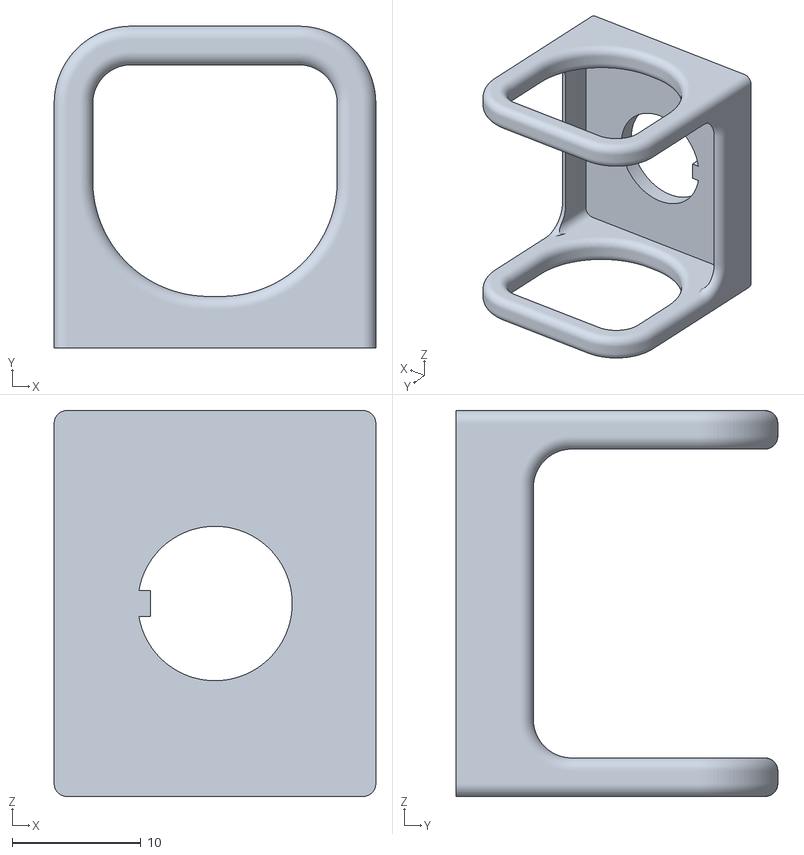
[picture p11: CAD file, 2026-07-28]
stl/nasa switch guards/space-shuttle-switch-guard.stl
25.0 x 25.0 x 30.0

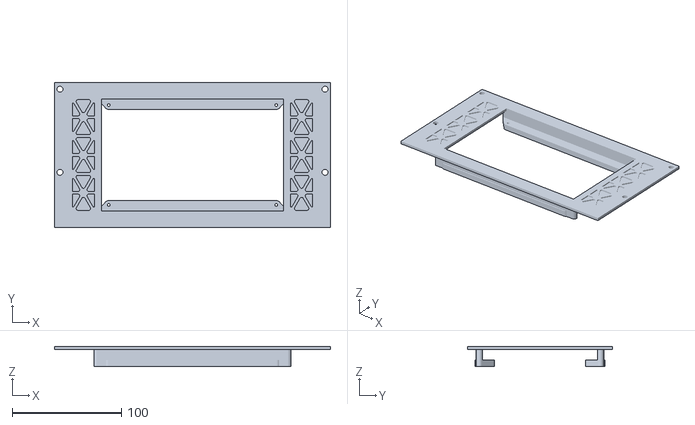
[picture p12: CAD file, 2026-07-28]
Console10_display_faceplate.stl
253.0 x 133.3 x 18.4

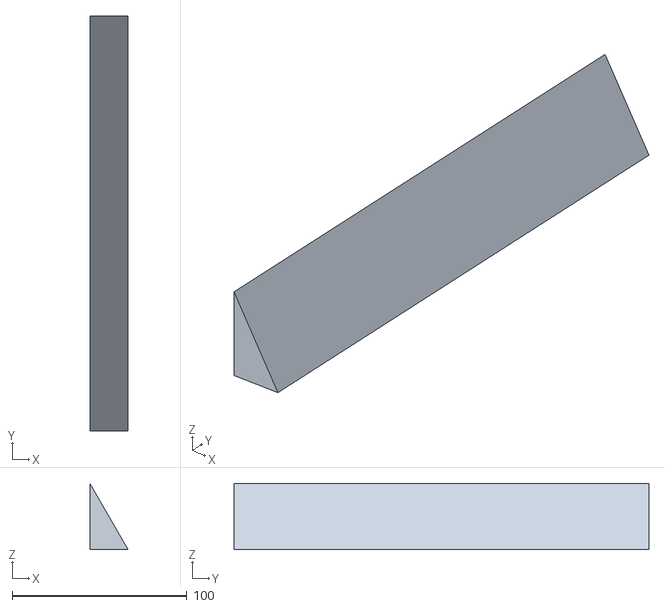
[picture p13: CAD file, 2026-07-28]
preview/front_check.stl
21.9 x 237.2 x 38.0

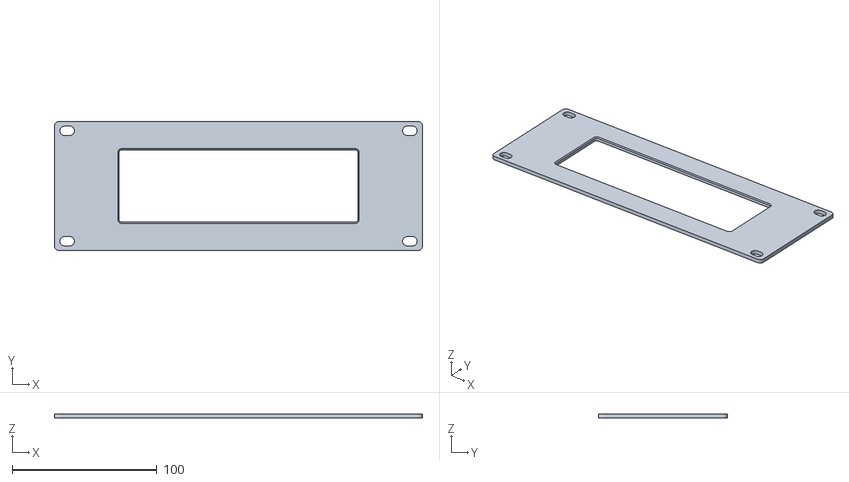
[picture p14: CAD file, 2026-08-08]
stl/Console10_b860i_faceplate.stl
254.0 x 88.9 x 3.00

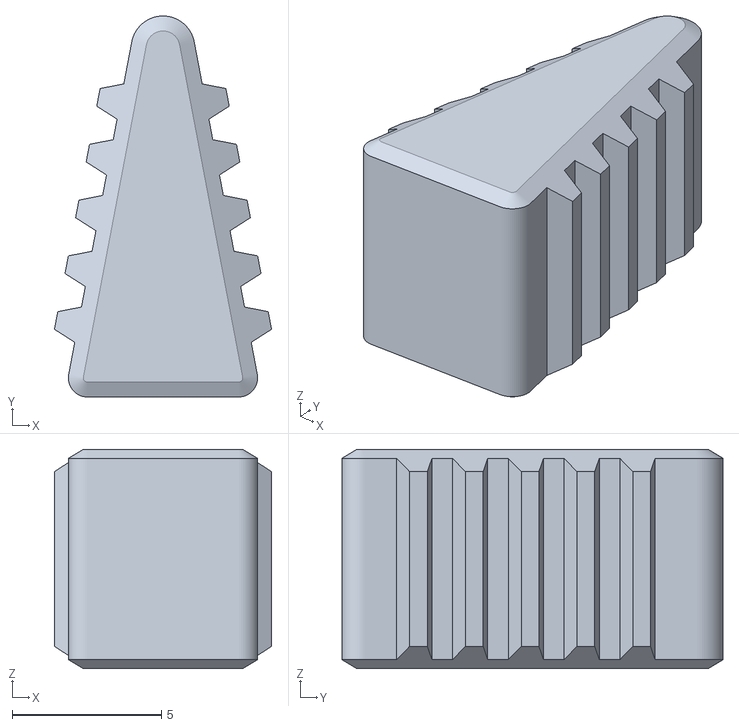
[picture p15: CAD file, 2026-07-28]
stl/nasa switch guards/space-shuttle-switch-head.stl
7.27 x 12.8 x 7.34

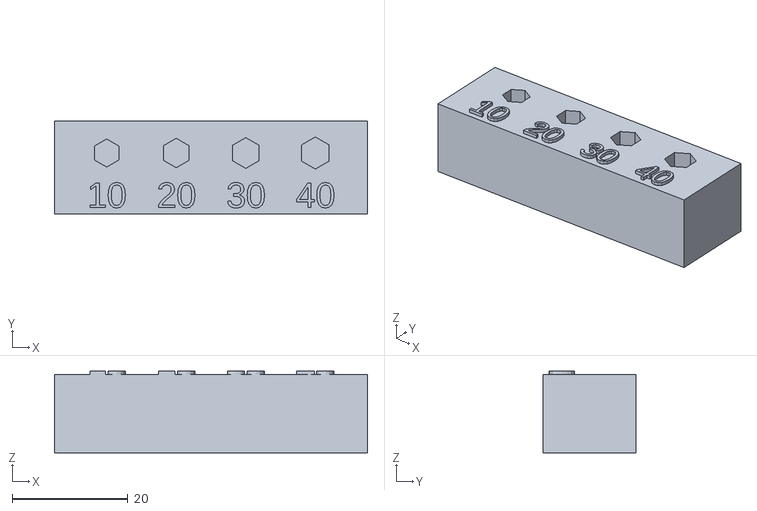
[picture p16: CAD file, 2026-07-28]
Console10_bit_hex_test.stl
54.0 x 16.0 x 14.1

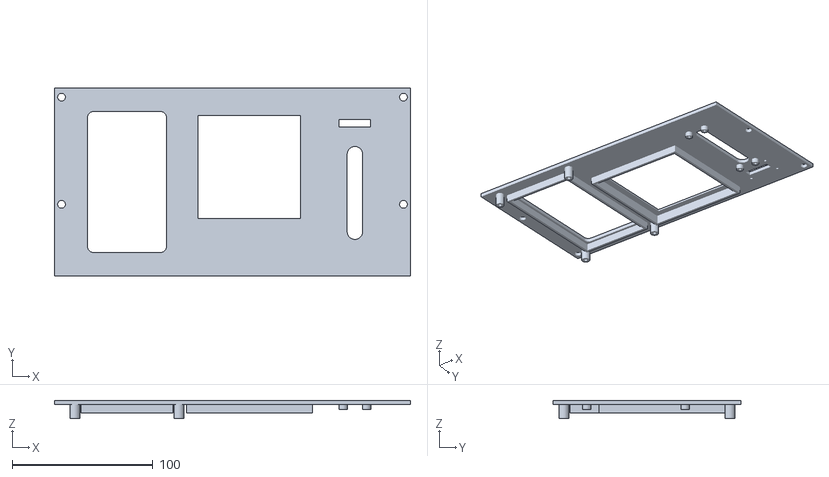
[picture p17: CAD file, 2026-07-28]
preview/dsky.stl
253.0 x 133.3 x 13.0

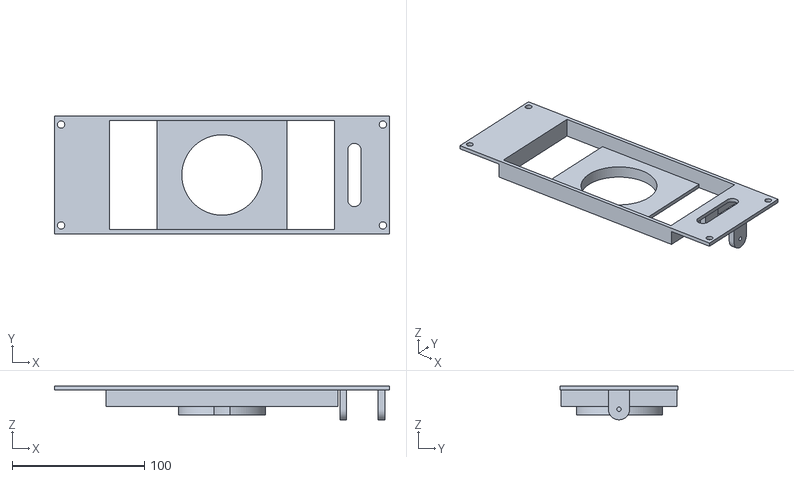
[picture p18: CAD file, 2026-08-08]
stl/Console10_phone_2u_panel.stl
253.0 x 88.9 x 25.4

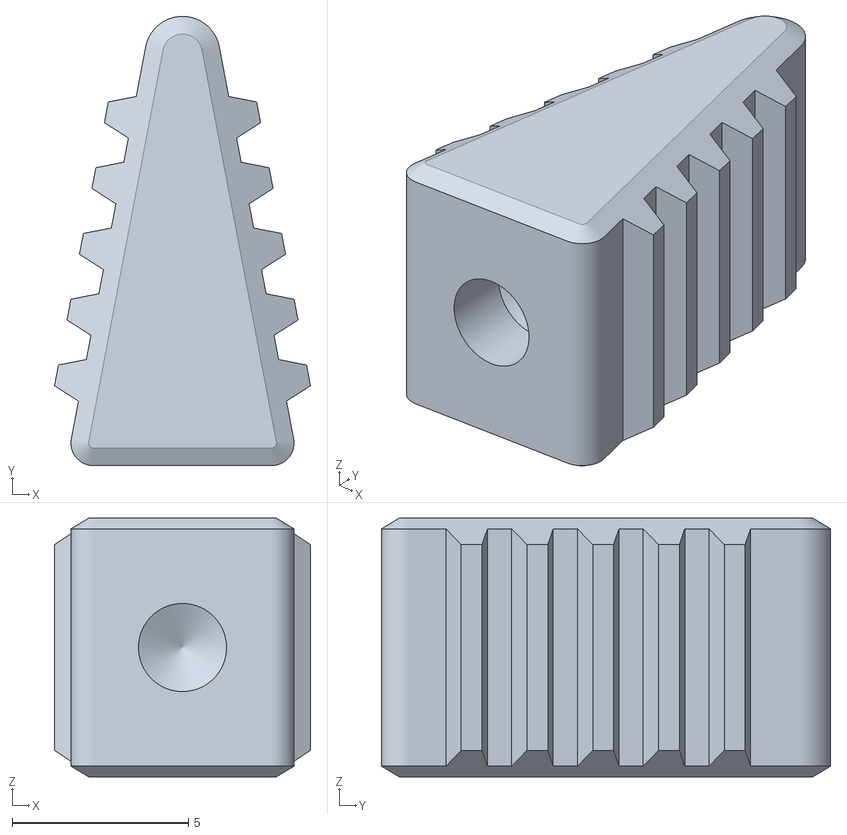
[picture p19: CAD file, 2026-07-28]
stl/nasa switch guards/space-shuttle-switch-head-with-hole.stl
7.27 x 12.8 x 7.34

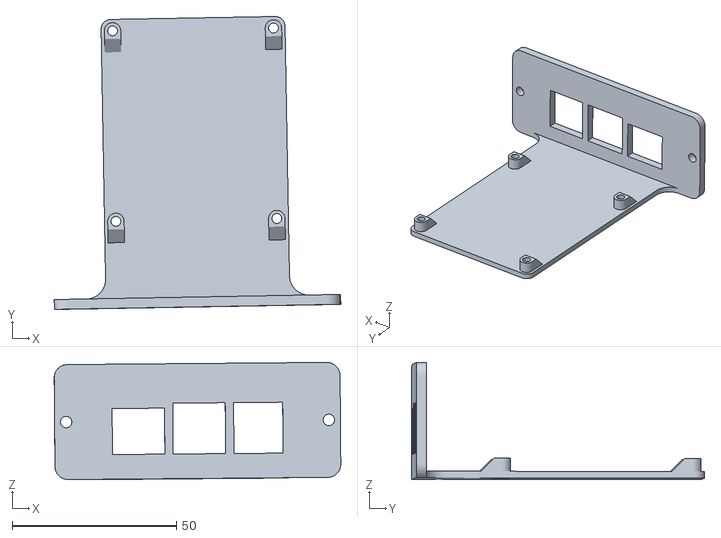
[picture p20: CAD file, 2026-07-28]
pi5bracket.stl
87.3 x 89.2 x 35.7

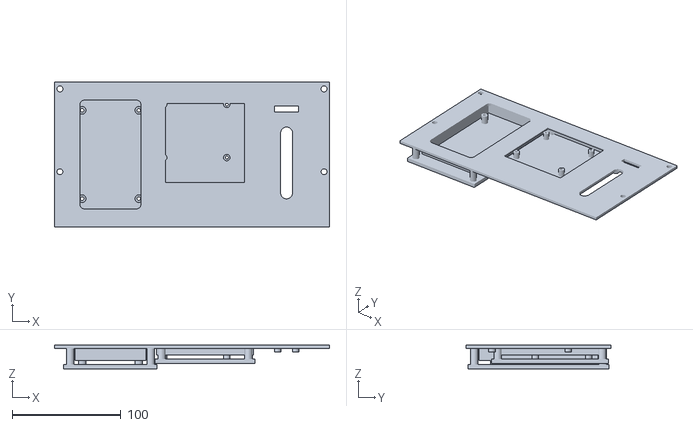
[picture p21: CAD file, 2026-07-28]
preview/dsky_panel.stl
253.0 x 133.3 x 22.0

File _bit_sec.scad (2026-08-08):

use <Console10_bit_holder_handled.scad>
STL="C:/3d files/Gridfinity/1x1x4_sd_card_holder_7.stl";
intersection(){
  difference(){ union(){ import(STL,convexity=8); slot_fill(); } bit_grid(); }
  translate([-1000,0,0]) cube([2000,2000,2000],center=true);   // keep X<0, view X=0 face
}
color("red")    translate([-0.3,0,24]) cube([0.6,60,0.25], center=true);
color("green")  translate([-0.3,0,23]) cube([0.6,60,0.25], center=true);
color("blue")   translate([-0.3,0,22]) cube([0.6,60,0.25], center=true);

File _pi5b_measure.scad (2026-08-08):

// Measurement aid — overlay axes on the rotated bracket
include <pi5bracket_edit.scad>

// Origin marker (red)
color("red") sphere(d = 3);
// +X axis (red), 60 mm
color("red")   translate([30, 0, 0]) cube([60, 1, 1], center = true);
// +Y axis (green), 60 mm (forward toward viewer in OpenSCAD Front view)
color("green") translate([0, 30, 0]) cube([1, 60, 1], center = true);
// +Z axis (blue), 60 mm (up)
color("blue")  translate([0, 0, 30]) cube([1, 1, 60], center = true);

// 10 mm tick marks on each axis
for (i = [10, 20, 30, 40, 50]) {
    color("red")   translate([i,   0, 0]) cube([0.5, 4, 0.5], center = true);
    color("green") translate([0,   i, 0]) cube([4, 0.5, 0.5], center = true);
    color("blue")  translate([0,   0, i]) cube([4, 0.5, 0.5], center = true);
}

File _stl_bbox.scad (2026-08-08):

// nothing; bbox not directly available — rely on the section render

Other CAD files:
stl/Console10_phone_2u_lever.stl
Console10_isogrid-new.stl
preview/hp_sq.stl
stl/Console10_phone_2u_ejector.stl
_stl_sec.scad
Console10_4wide.scad
Console10_aux_2u_faceplate.scad
Console10_aux_2u_faceplate_edit.scad
Console10_aux_2u_faceplate_v02.stl
Console10_b860i_faceplate.scad
Console10_bit_hex_test.scad
Console10_bit_holder_handled.scad
Console10_bit_holder_handled.stl
Console10_blank_2u.scad
Console10_bluray_2u_faceplate.scad
Console10_bluray_2u_faceplate.stl
Console10_bottom.scad
Console10_bottom_panel_half.scad
Console10_display_faceplate.scad
Console10_display_faceplate_v015.stl
Console10_display_faceplate_v017.stl
Console10_display_faceplate_v018.stl
Console10_drawer.scad
Console10_dsky_panel.scad
Console10_front_insert.scad
Console10_guard_bank3.stl
Console10_hyperpixel_sq_faceplate.scad
Console10_isogrid.scad
Console10_isogrid_vent.scad
Console10_lcd_simple_faceplate.scad
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

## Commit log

2026-05-17 Initial commit: Console10 v2.2
    Modular desktop 10" mini-rack housing system, NASA MOCR-themed.
    Trapezoidal silhouette, isogrid cheek panels, Apollo-style castellated
    finger-joint seams. Conforms to 10" mini-rack standard (Geerling /
    Project MINI RACK) for housing small-form-factor homelab gear.
    See designdoc.md (v2.2) for the locked spec.
    Project migrated from web-Claude session downloads.
    [Console10_isogrid.scad, Console10_isogrid.stl, Console10_rail.scad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]
2026-05-17 Remove v2.1-era artifacts
    Drops side.stl, side-test1.stl, side.svg (one-off experiments) and
    Console10_rail.scad (per designdoc v2.2 sec 13 â€” rails are now
    integrated into the cheek; standalone rail part is no longer used).
    [Console10_rail.scad, side-test1.stl, side.stl]
2026-05-17 Update slant angle to 30° for isogrid alignment (v2.3)
    Changes the cheek slant from atan(0.5) = 26.57° to atan(√3/3) = 30°
    from vertical. The new angle aligns the slant edge exactly parallel to
    one set of {3,6} isogrid triangle edges, eliminating the 3.43° visual
    delta visible in v2.2. Ergonomically negligible (3.43° more recline,
    still well inside the desktop console comfort zone).
    Cascading dimension changes:
    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
    [Console10_isogrid.scad]
2026-05-19 Console10 v2.5: isogrid pocket filter (cheek)
    v2.3 -> v2.5 jump (v2.4 was never committed).
    Cheek (Console10_isogrid.scad):
    - v2.4 architectural changes integrated: thickness 6 -> 10 mm,
    rail mount holes relocated to slant + back edge faces (axis
    perpendicular to edge), top + bottom channels cut into cheek
    interior face along top + bottom edges.
    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
    [Console10_isogrid.scad]
2026-05-28 Console10 v3.1: parametric parts + symmetric ridge joinery
    - Re-author top/bottom/front/cheek as parametric OpenSCAD + module assembly
    - Symmetric ridge joinery: top now matches bottom (slab + side ridges into
    cheek top rabbets); cheek rabbeted on both top and bottom edges
    - Front insert spans between cheeks, 30deg face flush with the slant
    - Sync designdoc + README to v3.1; drop superseded isogrid.stl + old previews
    [Console10_bottom.scad, Console10_front_insert.scad, Console10_isogrid.scad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]
2026-05-28 Console10 v3.3: bevel, M3 mounts, equal tongue/groove, exterior isogrid
    - Top front edge beveled to the slant (hull-built)
    - M3 counterbored socket-cap mounts: top 3/side, bottom 4/side, into heat-set
    inserts in the cheek top + bottom edges
    - Tongue/groove equalized to 10/3 (~3.33 mm), centered / all-equal
    - Isogrid moved to the EXTERIOR face, 5 mm deep, outer ring filled (iso_edge_fill)
    - Front insert spans between the cheeks; designdoc synced to v3.3
    [Console10_bottom.scad, Console10_isogrid.scad, Console10_top.scad]
2026-05-28 Console10: add v3.3 part STL exports
    Exported from the parametric SCAD: cheek, top, bottom, front insert.
    [Console10_bottom.stl, Console10_cheek.stl, Console10_front_insert.stl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]
2026-05-28 Console10: add WIP display faceplate (recessed 7" 1024x600 mount)
    Parametric 3U faceplate for the ELECROW RC070 7" touch (B08FMNDDSL), Pi-on-back.
    Recessed/flush window built to the known active area (164.7x107.1 mm); pocket
    size, front-frame depth, and corner-hole pattern are placeholders to confirm
    with calipers on arrival. Right-side port relief; 2 rack screws/side.
    [Console10_display_faceplate.scad]
2026-05-30 Console10: display faceplate v0.15 — 3 mm flat panel, flush LCD
    Replace v0.6 design: LCD body now sits BEHIND a uniform 3 mm slab,
    glass flush at the front face. Mount structure:
    - Top + bottom rear support walls (boss-to-boss, flush against the
    LCD PCB), widened in Y so they merge with the connecting walls
    - Connecting walls outside the LCD opening on each row, extending
    from the support foot up to the slab back
    - 4 corner L-brace arms tying boss positions to the connecting walls
    - Left/right edges left open — RC070's HDMI / USB / CK220 cap /
    scroll wheel / headphone jack live on those edges
    - v0.6's cable relief removed (connectors clear behind the panel)
    Console10_module: wire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
    [Console10_display_faceplate.scad, Console10_display_faceplate_v015.stl, Console10_module.scad]
2026-05-30 Console10: add slide-out Gridfinity drawer v0.2
    2U slide-out drawer for the bottom of a Console10 module. Drawer
    floor is a true Gridfinity baseplate (42 mm grid, 4.75 mm interface)
    so off-the-shelf bins drop in. Faceplate-anchored architecture — the
    slanted faceplate (bolts to the cheek rack inserts) carries integral
    C-channel slide rails; nothing touches the bottom panel. Drawer's
    30 deg front nests flush in the faceplate mouth when closed,
    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
    [Console10_drawer.scad]
2026-05-30 Console10: Stream Deck Mini 2U faceplate v0.8 — 4 devices
    2U faceplate hosting four devices left-to-right with auto-spaced
    horizontal centers (chain math from a shared panel_layout_gap):
    - CF reader: press-fit, full-depth open sleeve (13.8 x 65.9 x 30)
    - SD card holder: slides into front, sits 5 mm proud, closed-back
    sleeve floor as the bottom-out stop (41.5 x 41.5 STL footprint)
    - Elgato Stream Deck Mini: proud bezel mount, 54 x 34.7 button-area
    cutout, 4 rear corner snap clips
    - QIANRENON USB-C panel mount: 17 x 23 body cutout + 2 M3 screw
    holes 30 mm CC, 3.6 mm flange proud of panel front
    Includes Console10_streamdeck_faceplate_v008.stl panel-only export.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
    [Console10_streamdeck_faceplate.scad, Console10_streamdeck_faceplate_v008.stl]
2026-05-30 Console10: display faceplate v0.16 — add HDMI switch slot
    Add vertical HDMI switch slot to the left of the LCD opening. The
    QIANRENON-style HDMI switch is mounted with its long axis vertical:
    11.02 mm wide x 75.2 mm tall cutout on the panel face, rear sleeve
    35 mm deep (open both ends — slides in from front or back). Two M2
    clearance holes are drilled by a single X-axis cylinder through both
    side walls, positioned 6.6 mm down from the top end of the sleeve
    to clamp the device's mounting points.
    5 mm visual gap between the LCD opening edge and the HSW sleeve
    outer wall. Sits cleanly within the LCD-to-cheek horizontal margin.
    Includes Console10_display_faceplate_v016.stl panel-only expor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
    [Console10_display_faceplate.scad, Console10_display_faceplate_v016.stl]
2026-05-30 Console10: split aux faceplate into LCD-simple (3U) + aux 2U
    Stream Deck panel had grown into a multi-device aux faceplate (CF +
    SD holder + USB-C + Stream Deck + later a big LCD hole). Splitting
    into two purpose-built panels:
    - Console10_lcd_simple_faceplate.scad (3U): single 84.1 × 84.1
    cutout for an LCD, slant-mount holes only, no rear features.
    Exported as Console10_lcd_simple_faceplate_v01.stl.
    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
    [Console10_aux_2u_faceplate.scad, Console10_lcd_simple_faceplate.scad, Console10_lcd_simple_faceplate_v01.stl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]
2026-05-30 Console10: aux 2U v0.2 — 3 holders + USB-C far right
    CF stays on the left, 3 SD-card holders grouped consecutively, USB-C
    anchors the far right. Layout symmetric around X=0 with 10 mm gaps
    between adjacent device outer footprints.
    - cf_cx shifted left to -99.25 to balance the row
    - holder_cxs = [-56.6, -0.1, +56.4]
    - usbc_cx = +99.15
    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
    [Console10_aux_2u_faceplate.scad, Console10_aux_2u_faceplate_v02.stl]
2026-05-31 Console10: display faceplate v0.17 — HSW resized + U-rail end walls
    HDMI switch dimensions updated to measured values: 17.2 × 110.2 ×
    11 mm (was 11.02 × 75.2 × 35). LCD shifted right by 13.6 mm so the
    (HSW + LCD) composition is centered on X=0.
    Rear sleeve restructured:
    - Top + bottom end walls extend back hsw_end_wall_d = 75.4 mm
    (was uniform with the L+R walls)
    - L + R side walls stay short at hsw_d = 11 mm
    - 4× 6 mm inward U-rail lips added at the X edges of the top and
    bottom walls — creates U-channel cross-sections opening inward
    - M2 set-screw holes still drilled through the short L+R side walls
    Includes Console10_display_faceplate_v017.stl panel-only export
    (replaces v0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
    [Console10_display_faceplate.scad, Console10_display_faceplate_v016.stl, Console10_display_faceplate_v017.stl]
2026-05-31 Console10: display faceplate v0.18 — LCD mount-hole pitch fix + 2x HSW bracket walls
    - LCD corner mounting holes: pitch corrected to caliper-measured 153.6 x 91.5 mm (was 157.64 x 94, derived from the glass face via one hole_inset estimate). hole_dx/hole_dy are now independent measured constants so a bezel change can't drag them off-spec again.
    - HDMI-switch bracket: top + bottom end walls thickened 2x (2.5 -> 5 mm), grown outward so the device cavity and fit are unchanged.
    [Console10_display_faceplate.scad, Console10_display_faceplate_v018.stl]
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2026-06-07 Add Console10 hex bit holder (recreated from the SD-holder bin)
    Built from the same Gridfinity bin import so the standard stacking base and
    recessed top tray are preserved. The SD slots are filled flush to the tray
    floor and replaced with a 5x4 grid of 4mm hex bit pockets (0.20 mm/side,
    11 mm deep). Same sci-fi U grab-handles.
    [Console10_bit_holder_handled.scad, Console10_bit_holder_handled.stl]
2026-06-11 Fix vestigial SD slots in hex bit holder
    The bit holder fills the imported SD-card holder's slots via slot_fill(), but
    FILL_Z0 was 18 — only the slot tops were filled, leaving the lower slots (which
    run from the floor down into the base region) as vestigial interior voids.
    - FILL_Z0 18 -> 2: fills the full slot depth. Verified the Gridfinity base
    underside (flat base + 4 corner holes + lip) is identical at FILL_Z0 2 vs 4.75,
    so the base is untouched; hex pockets intact.
    - Wrap part in module bit_holder() + SECTION diagnostic flag (defaults to full).
    - STL re-exported: Simple: yes, Volumes 9 -> 2.
    - .3mf left stale (re-slice when printing).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
    [Console10_bit_holder_handled.scad, Console10_bit_holder_handled.stl]
2026-06-14 Console10: add twin-MacroPad panel + single-piece mounting board
    Twin Adafruit 5128 MacroPad lower faceplate, two boards end-to-end. New
    macropad_mount_board(): one plate spanning both pads that bridges the two
    bolt circles -- bolts down onto all 8 panel posts (outboard, +/-38 x +/-44)
    and carries 8 standoffs up to the PCB holes (+/-26.04 x +/-40.64). The two
    circles are intentionally non-concentric (Ø7 posts clear the pocket wall).
    Replaces the two loose per-pad backplates; old macropad_backplate() kept for
    reference. part = "panel" | "mount_board" | "macropad_backplate".
    Exported STLs + designdoc section 16.
    [Console10_macropad_pair_backplate.stl, Console10_macropad_pair_faceplate.scad, Console10_macropad_pair_faceplate.stl]
2026-06-14 Console10: fix MacroPad mount-board standoffs (holes not board-centred)
    The 5128 mounting-hole pattern is NOT centred on the PCB -- measured from the
    assembly STL (PCB cross-section overlaid in OpenSCAD) it sits +7.65 mm toward
    the OLED/encoder end. v0.2 placed standoffs centred (+/-mp_hy), missing every
    hole by ~7.6 mm and making back-to-back mounting impossible.
    Add mp_hy_off=7.65; standoffs + MP screw holes now at (+/-mp_hx, +/-mp_hy +
    mp_hy_off). Plate widened to +/-106.4 to support the OLED-end standoffs.
    Overlay check: residual <0.1 mm at all 4 holes. designdoc s16 -> v0.3.
    [Console10_macropad_pair_backplate.stl, Console10_macropad_pair_faceplate.scad]
2026-06-14 Console10: add screen+slider+OLED panel; CAD-accurate NeoSlider/OLED dims
    - New Console10_screen_slider_panel.scad: HyperPixel 4" square + NeoSlider
    fader + 0.91" OLED; MacroPad removed and the two device groups re-centred.
    - OLED recessed in a module-sized rear pocket so the glass sits ~0.5 mm behind
    the front lip (the display module is larger than the active window).
    - Slider + OLED PCBs touch; slider bottom 5 mm below the screen's bottom edge.
    - NeoSlider/OLED dims pulled from Adafruit STEP CAD (Adafruit_CAD_Parts): fixes
    the slider mounting-hole spacing (was 70 mm, actually 38.1 mm) and housing
    footprint (now 75 x 9.5, top 6.5 mm proud); synced into the DSKY panel too.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
    [Console10_dsky_panel.scad, Console10_screen_slider_panel.scad]
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2026-06-14 Console10: README — cabinet-vs-accessories framing + accessory faceplate list
    - Clarify "Console10" = the cabinet (cheeks + top + bottom); the panels are swappable
    accessory faceplates that bolt to the slant / back-edge inserts.
    - Add an accessory-faceplate table (display, lower-blank, MacroPad pair, screen/slider,
    DSKY, drawer) with mount + status.
    - Mark Console10_module.scad as built (fit-check assembly); sync designdoc ref to v3.3.
2026-06-17 Twin-MacroPad panel v0.2: guarded switch row + fused 3-gang guards
    - Add a row of 6 guarded toggle switches in the lower skirt (Y=42), placed in the
    gaps between mount-board posts so bodies foul only the board (relieved per switch).
    - Remove the OLED status display and its mounting features.
    - Fuse the space-shuttle flip guards into two 3-gang banks (guard_bank, part="guard_bank");
    rotate so the cages read vertical and overlap into one part.
    - Replace the six square recesses with two sharp-cornered gang locating pockets
    (86 x 25 mm + 0.5 clr, 2.5 mm deep) plus the 6 toggle bushing holes.
    - Export deliverables: panel, mount board, and the fused 3-gang guard (print x2).
    - Add Console10_m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
    [Console10_guard_bank3.stl, Console10_macropad_mount_board.stl, Console10_macropad_pair_faceplate.scad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]
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2026-08-08 Docs audit v3.3.1: cabinet = 4 parts; slant-cap flag; headless export params
    - README/designdoc: front slant insert reclassified as an accessory
    (cabinet = 2 cheeks + top + bottom); parts tables point at stl/
    exports; stale open-items closed.
    - Console10_module.scad: CABINET_PARTS/ACCESSORY_PARTS authoritative
    lists; slant cap gated behind show_slant_cap (was drawn
    unconditionally).
    - macropad_pair_on_slant gains with_devices/with_backplate params so
    headless exports can skip non-manifold fit-check mocks.
    - wip/_parts.py committed: it parses the part lists with no fallback,
    so it travels with the file it parses.
    [Console10_macropad_pair_faceplate.scad, Console10_module.scad]
2026-08-08 Track B860-I faceplate + ventilated cheek; sync README catalog
    - Console10_b860i_faceplate.scad (+stl): 2U cover plate for the ASUS
    B860-I rear I/O (truenas2 build).
    - Console10_isogrid_vent.scad (+stl): cheek variant with the isogrid
    field cut through for airflow; drop-in cheek() swap, mirrors
    Console10_isogrid.scad.
    - README: accessory + layout tables gain rows for these, the phone dock
    panel, marketing/, and wip/.
    [Console10_b860i_faceplate.scad, Console10_b860i_faceplate.stl, Console10_cheek_vent.stl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]
2026-08-08 Track deprecated split-half panels for the record
    README has listed both as DEPRECATED since v3.0 but they were never
    committed; tracked once so the reference resolves in history.
    [Console10_bottom_panel_half.scad, Console10_top_panel_half.scad]
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

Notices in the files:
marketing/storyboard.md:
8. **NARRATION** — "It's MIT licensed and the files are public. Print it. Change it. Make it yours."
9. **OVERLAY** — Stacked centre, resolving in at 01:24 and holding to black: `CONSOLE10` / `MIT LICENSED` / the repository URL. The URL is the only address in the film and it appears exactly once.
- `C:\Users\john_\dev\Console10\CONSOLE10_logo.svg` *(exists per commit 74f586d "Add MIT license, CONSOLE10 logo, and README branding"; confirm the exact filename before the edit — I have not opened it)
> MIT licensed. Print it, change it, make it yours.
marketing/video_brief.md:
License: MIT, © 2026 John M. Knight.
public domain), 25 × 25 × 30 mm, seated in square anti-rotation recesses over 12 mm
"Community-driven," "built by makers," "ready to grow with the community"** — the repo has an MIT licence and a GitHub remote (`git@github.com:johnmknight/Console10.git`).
